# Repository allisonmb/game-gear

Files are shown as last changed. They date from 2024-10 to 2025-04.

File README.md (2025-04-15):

# Production Release - Game Gear
Our project was focused on recreating the original experience of the SEGA Game Gear handheld console with modern hardware and improved functionality.

[Build Instructions](Build%20Instructions.pdf)

[Bill of Materials](Bill%20of%20Materials.pdf)

[Raspberry Pi Image](https://drive.google.com/drive/u/0/folders/1cTOPLiqQtfveVBptVOEDtFShPZntb5K-)

Each aspect of the project is linked below, with README files indicating their functionality, how to run them, and known bugs.
- [Emulator ROM Implementation](romDev/)
- [Cartridge Auto Launch Scripts](romDev/udev_scripts/)
- [PCB Designs](https://github.com/allisonmb/game-gear/tree/17-pcb/pcbDesign)
- [GPIOnext](https://github.com/mholgatem/GPIOnext) - Used for interfacing with buttons through GPIO
- [3D Model](https://drive.google.com/file/d/1HNF1D_YHym1qWQATkMjLh69oOEiKL8Yn/view?usp=sharing) - Will need blender to view

Below are links to parts of the project that are no longer in development
- [FPGA Implementation](A-Z80/)
- [Z80 Assembly Test Code](<z80 assembly/>)

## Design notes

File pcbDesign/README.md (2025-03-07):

# PCB Design and Schematics
There are 3 PCBs: the left, right, and center PCBs. These are connected to eachother with header pins. Note: The "main PCB" is an old version which was before the PCB was split into 3. "GG PCB" is a remake of the original Game Gear PCB from https://oshwlab.com/maarten040476_3348/sega-game-gear-837-7996.
## Currently Implemented
### Center PCB
The center PCB connects to the left and right PCBs. 
The center PCB contains:
- [Raspberry Pi Zero W](https://www.raspberrypi.com/products/raspberry-pi-zero-w/)
- [3.5 Waveshare HDMI Screen](https://www.waveshare.com/wiki/3.5inch_HDMI_LCD)

### Left PCB
The left PCB contains:
- D-Pad buttons - These are traces on the board that are not connected. They are connected by a metal disk attached to the button that completes the circuit when the button is pushed.
- Power LED - A 3mm red LED with a 270 ohm resistor.

### Right PCB
The right PCB contains:
 - Start, 1, and 2 buttons - Works the same as the D-Pad buttons

## To be Implemented
### Center PCB
- Batery PCB - Need to decide on exact battery and battery board that will provide enough power for the other components

### Left PCB
- Volume Dial - Connected to rotary encoder that can be interpreted by the Raspberry Pi to change the system's volume level.
- Audio Amplifier - Connected to the Raspberry Pi and is capable of converting digital sound to anologue to go to a speaker. Currently looking at using [MAX98357A](https://www.adafruit.com/product/3006)

### Right PCB
The right PCB contains:
 - Brightness Dial - Same implementation as the volume dial, except for the screen brightness

## Current Issues
- The PCB is not complete, the parts listed above need to be added
- There may be an issue with using the MAX98357 audio amplifier with the PiJuice. Both use i2c for communication with the Raspberry Pi. However, they use different pins to do so and thus both may work together.
- The battery must be large enough to support the Raspberry Pi and the HDMI screen. The power consumption for both needs to be measured to choose a big enough battery.
- The largest single cell battery that can fit in the current case is 1200mAh. It is unlikely this is sufficient to power the console. There are two possible fixes for this. The case can be altered to allow a larger signle cell battery to fit, but this would cause issues with holding the console. Or multiple batteries in series could be used, but this would eliminate use of some battery PCBs which only work with single cell batteries.

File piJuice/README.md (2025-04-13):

# PiJuice Battery Setup

## Note - Ensure pijuice board is connected to the pi for the entire setup. The battery itself does NOT need to be connected to the pijuice

## 1. Install Lite Version of PiJuice Software
```bash
sudo apt-get install pijuice-base
```

## 2. Run PiJuice CLI
```bash
pijuice_cli
```

## 3. Choose Battery Profile
- Navigate to `Battery Profiles`
- Select: **PjZero_1200**

## 4. Configure Power Switch
- Navigate to `Buttons`
- Select `SW2`
  - Under **Press**, select: `HARD_FUNC_POWER_ON`
  - Under **Release**, select: `HARD_FUNC_POWER_OFF`

## 5. Configure LED Script

### a. Enable `pijuice.service`
```bash
sudo systemctl enable pijuice.service
sudo systemctl start pijuice.service
sudo systemctl status pijuice.service
```

### b. Ensure `lowPowerLED.py` Has Correct Ownership and Permissions
```bash
chmod +x /home/pi/lowPowerLED.py
chmod 777 /home/pi/lowPowerLED.py
sudo chown pi:pi /home/pi/lowPowerLED.py
```

### c. Set Script to Run on Boot
- Run `pijuice_cli`
- Navigate to `System Events`
  - Enable **System Start**
  - Set function to: `USER_FUNC1`
- Navigate to `User Scripts`
  - Set `USER_FUNC1` to:
    ```
    /home/pi/lowPowerLED.py
    ```

## 6. Configure Low Power Shutdown

- Navigate to `System Tasks`
  - Enable **Min Charge** and set threshold to **10%**
- Navigate to `System Events`
  - Enable **Low Charge**
  - Set function to: `SYS_FUNC_HALT_POW_OFF`

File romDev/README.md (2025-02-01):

# Emulator ROM Implementation
As part of our prototype we are developing a simple test ROM to run a "Hello World" demo program on any Game Gear Emulator. We are using DevkitSMS for this which is a library that allows c code to be compiled into Sega Master System and Sega Game Gear files. This process involves using a tool called BMP2Tile to turn a BMP image into readable tile and palette formats. The program uses the library's SMS_loadPSGaidencompressedTiles(), SMS_loadSTMcompresssedTileMap, GG_loadBGPalette(), SMS_displayOn(), and SMS_waitForVBlank() methods to load and display the "Hello World" background. SMS_AddSprite() is used to display a sprite of a Gator head which polls input from the directional pad and buttons to move around and change its image.

### Current implementation for final product
[Retropie](https://retropie.org.uk/) and the [lr-genesis-plus-gx](https://github.com/libretro/Genesis-Plus-GX) Game Gear emulator are currently running the test rom on a Raspberry Pi Zero W. The controller to interface with the raspberry pi is custom using an Arduino Feather with [GP2040-CE](https://gp2040-ce.info/) firmware which makes any microcontroller with a RP2040 chip recognized as a controller via USB.

The following steps are to install and run retropie and the test rom on a Raspberry Pi Zero W. Please look at the official documentation for retropie to make adjustments if running on a different raspberry pi.
1. Using [Raspberry Pi Imager](https://www.raspberrypi.com/software/) install an image of retropie onto a micro sd card. In the imager, select Raspberry Pi Zero W as the device, Emulation and Game Os > Retropie > Retropie (RPI 1/Zero) for the OS, and the micro sd as the storage.
2. On boot, a welcome screen should apear followed by a controller configuration screen. Configure the controller based on the instructions on the screen.
3. Enter Configuration > WIFI on the main menu. Select No on the next screen. Then select 1 Connect to WiFi network. After completing the following prompts, the pi is connected to the network. Return to the main menu.
4. Enter Configuration > RASPI-CONFIG. Select 3 Interface Options > P2 SSH. Select yes to enable SSH.
5. Download [compileTest.gg](compileTest.gg) from this repo onto a computer.
6. Use sftp to transfer compileTest.gg from your computer to the raspberry pi. The pi's IP address can be found under Configuration > Show IP.
7. Ssh into the raspberry pi. User is pi default password is raspberry. (NOTE: For security, this default password should be changed.) Move the compileTest.gg from the home directory to /home/pi/RetroPie/roms/gamegear
8. Restart retropie. This can be done by accessing the retropie menu with the start button
9. Game Gear will now be an option from the main menu. Select it then the compileTest rom

### How to run test emulator without a raspberry pi
1. Install Sega Game Gear Emulator, Fusion recommended (https://www.emulator-zone.com/doc.php/genesis/fusion.html)
2. Run makefile to compile code (if not already compiled)
3. In Fusion click File->Load Game Gear ROM (CTRL-A) and load "compileTest.gg"
4. Use arrow keys and 'A' to control program

### Setting Up the external controller
1. Program "/Keyboard/Keyboard.ino" to Arduino
2. Flash "/Keyboard/Arduino-keyboard-0.3.hex" to Arduino
3. Unplug and Replug Arduino to have it appear as a keyboard

### Bugs/History
#### Initial test rom development (using fusion)
There were some bugs throughout the development. One common mistake is using the Sega Master System color palette for Game Gear games. The color palette scheme is one of the few major differences between the two. When programming, bugs were a bit hard to detect with no terminal output from the fusion emulator. Luckily though compilation was very quick, requiring only one make command, so changes could be quickly made and tested. When learning how to display sprites, it was helpful to display all tiles of a sprite at once, and then sort from there which were needed and where.
#### Raspberry Pi Setup
There was one main issue implementing retropie on the Raspberry Pi Zero W which is easily avoidable. The main issue was downloading the incorrect version of Retropie. This resulted in the pi booting straight to the terminal instead of into retropie. 
Some current issues with Retropie include:
- Booting into the retropie main menu. Ultimately, this will need to boot directly to a Game Gear ROM or menu specifically for the Game Gear
- There are other emulators in retropie that are loaded on boot but are never used for this project. These need to be removed from the retropie install to reduce boot time and save space
- There is currently no exit built into the test rom. When running in retropie the test rom must be exited using the retroarch menu which is accessed using a hotkey configured at retropie's first boot. [Here is more information on the hotkey](https://retropie.org.uk/docs/Controller-Configuration/#hotkey)
- Using the GP2040-CE firmware on the Adafruit feather is not ideal. Significantly fewer gpio pins are configured on the Adafruit feather when installing the pico's version of the firmware on it (there is no adafruit feather version of the firmware). Thus, only 6 buttons can be configured on the custom controller with the Arduino Feather. The Game Gear has a total of 8 buttons. This is easily fixed by replacing the Adafruit Feather with a Raspberry Pi Pico

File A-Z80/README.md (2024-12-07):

# FPGA Implementation: A-Z80
Towards our goal of a realistic Game Gear representation, we intend to use an FPGA to replicate the Z80 and other boards such as the proprietary sound board. The [A-Z80](https://github.com/gdevic/A-Z80) does this, although it is somewhat outdated and does not have all of the functionality we need. However, it provides a full implementation of the Z80 along with some testing files. The implementation had to be updated from one that works on MAX II hardware to modern MAX 10 hardware (which is a jump from Quartus 13.0 to Quartus 23.1). As a result, the RAM and PLL (for the clock) had to be recreated in modern Quartus. Ultimately, this code is capable of converting a Z80 assembly file into a machine code memory initialization, synthesizing a memory and UART module, and then programming a DE10 Lite to replicate a Z80 that is running assembly code. The [provided test case](tools/zmac/hello_world.asm) is a "Hello World" implementation, which outputs printed statements over UART (in this case "CpE Design").

## How To Compile Assembly
1. Create and develop a Z80 assembly file in the [zmac folder](tools/zmac) (or use the provided [hello_world.asm](tools/zmac/hello_world.asm)).
2. Drag and drop the created assembly file onto [make_fpga.bat](tools/zmac/make_fpga.bat).
3. Proceed with synthesizing and programming below.

## How to Synthesize and Program the DE10 Lite
1. Open the DE10 Lite Quartus project located [here](host/basic_de1/basic_de1.qpf).
2. Ensure that the DE10 Lite development kit is selected as the board.
3. Ensure the pins are correctly assigned according to the [DE10 Lite manual](https://ftp.intel.com/Public/Pub/fpgaup/pub/Intel_Material/Boards/DE10-Lite/DE10_Lite_User_Manual.pdf).
4. Click the play sign at the top to perform synthesis, planning, and routing.
5. Open the Programmer and select the USB-Blaster device.
6. Remove the default file for programming and click add file. Then, navigate to output_files and select the .pof file.
7. Program the board.
8. Proceed to use the programmed FPGA.

## Using the Programmed FPGA (For the provided hello_world.asm)
- KEY0 will act as a reset, immediately resetting the programmed output (along with the counter).
- KEY1 will act as a non-maskable interrupt, spamming "IM2" and then continuing after KEY1 is released.
- The UART output can be visualized using a DAD board with WaveForms (through the 'protocol' menu), and will be on GPIO pin 6, with a baud rate of 115200, 8 data bits, 1 stop bit, no parity, and a CR LF as the end of line.

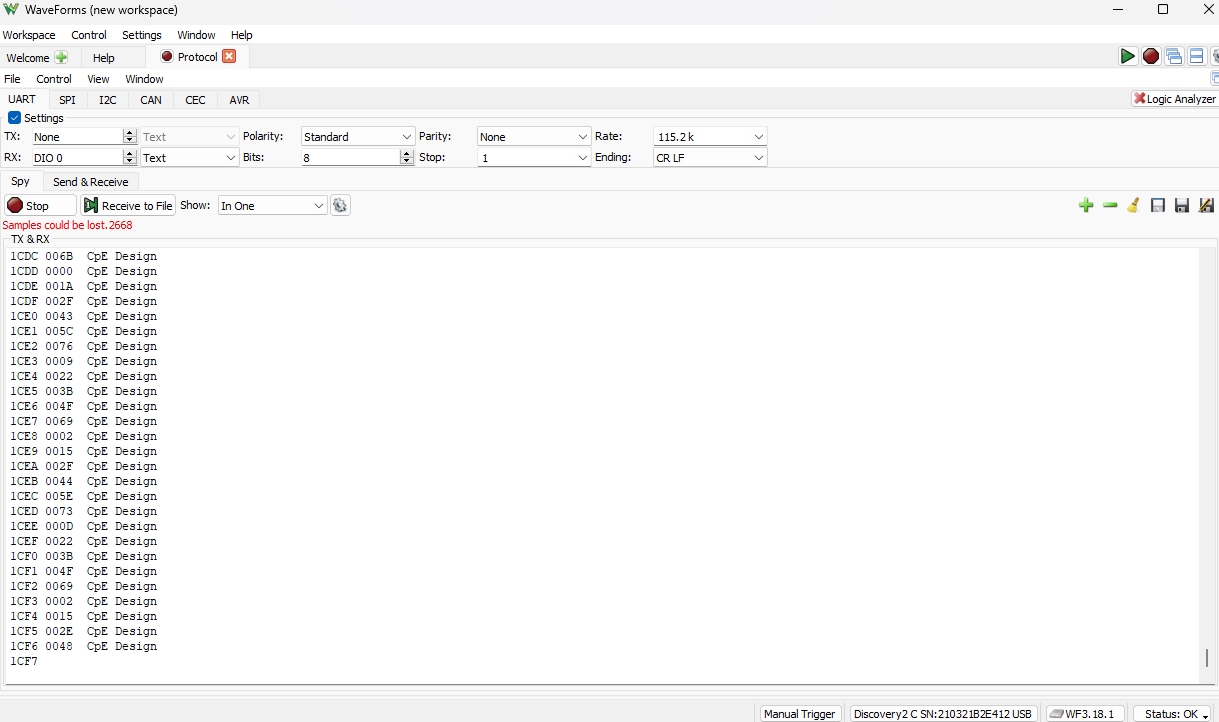
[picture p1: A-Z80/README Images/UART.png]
UART Output

## Experimentation/Difficulties
I struggled significantly with getting the A-Z80 code to run on any other board. At first, I tried the OOTB MAX 10 FPGA that was provided in Digital Logic, but was not able to get it to run even after many hours of modification. Ultimately, I realized this was because the particular model we were using did not support memory intiialization, and thus it was not possible to create a RAM to store the assembly and machine code that needs to run on the Z80. While I could program the OOTB FPGA with the A-Z80, I could not get any assembly code to run. As a result, I had to track down a DE10 Lite board (from Digital Design), which has the capability to create a RAM, along with several other useful features such as having switches, buttons, and VGA.

However, even with the DE10 Lite, there were still significant struggles. For some reason the A-Z80 implementation was made with the DE1 board in mind, which is in the MAX II family. This is an archaic board that is only supported by archaic versions of Quartus (when it was still called Altera Quartus), and my modern version of Quartus basically just told me to it couldn't do anything with respect to converting. As a result, I had to dig through the files myself, install Quartus 13.0sp1 (wow it's so old), and try to understand how to best recreate the IP files (RAM and PLL) in modern Quartus. For a while, it was hard to tell whether the struggles I was having were due to improper configuration of the codebase, errors due to the conversion to MAX 10, or something else. This was a bit of a nightmare to debug, and at first I just focused on getting the ModelSim implementation to work (which actually didn't take too long). Then, I eventually managed to get the DE10 Lite to output something that seemed like UART, although it wasn't recognized by WaveForms. Eventually, I realized that the RAM was still improperly configured, and managed to get Hello World to successfully print. Since then, I have also explored the possibility of video output (particularly through VGA), but the issue is that the existing implementation of VGA bases its timings on 24 MHz and 27 MHz clocks that were present on the DE1 board. However, the DE10 only has 10 MHz and 50 MHz clocks, and the VGA protocol is extremely sensitive to timing. As a result, implementing VGA video output would be a very complex endeavour. Furthermore, we aren't planning on using VGA in our final solution, so we decided to instead focus on other interfaces like UART, SPI, and I2C that we would actually use for our screen.

## Known Bugs/History
Synthesis can be a bit finicky in Quartus, and so some errors may appear on different versions of Quartus or with different FPGAs other than the DE10 Lite. This code will not run on boards that are not in the MAX 10 family without a decent amount of modification. Getting the UART code to properly output was challenging, but I was finally able to do so after significant trouble with porting from MAX II (which modern versions of Quartus do not support and cannot convert) to MAX 10. Ultimately, I had to delete the IP files and recreate them with as similar of settings and initializations as I could, and it took some trial and error. Thus, porting to other families may be similarly difficult. When starting Quartus, it may prompt to overwrite or update the database file from another version of Quartus, and this is normal and can be accepted.
   Additionally, there were some issues modifying the [UART test code](tools/zmac/hello_world.asm) to add load instructions to store the string in memory instead of using db, since in many applications the data may be loaded instead of being constant before sending it to a communication protocol. When adding additional load instructions, instructions at the end of the function block were skipped preventing the whole string from loading. This is possibly an issue with the eZ80Acclaim IDE which was used for debugging, but it is more likely to be a logic error in the assembly.

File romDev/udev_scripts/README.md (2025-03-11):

# Cartridge Auto Load Scripts
This directory contains the udev rule and correponsing systemd services and scripts to enable the automatic cartridge loading functionality of our system. When the user plugs in a cartridge, the cartridge is mounted, the .gg ROM file is found, and the ROM file is automatically loaded into the emulator. In addition, when the cartridge is removed the emulator will automatically quit.

# How to Use
1. First, copy the udev rule (99-external-storage.rules) from the etc/udev/rules.d folder to the corresponding directory (/etc/udev/rules.d) on the system. Make sure to change the hard-coded directories to have the right username.
2. Then, copy the systemd rules from etc/systemd/system/mount-cart@.service and etc/systemd/user/run-cart@.service to the corresponding directories. Once again, update the home directory usernames to match the current system.
3. Lastly, copy the scripts from the /home directory to the user's home directory (/home/*user*).
4. Restart to let the rules take effect, or run the following command: `sudo udevadm control --reload-rules && sudo udevadm trigger && sudo systemctl daemon-reload`.
5. Then, the udev rules should be fully functional.

# Known Bugs/Future Steps
Right now, this implementation looks for any USB device when deciding what to mount. Once we have the JoeyGG, we intend to expand the script by restricting it to only the UUID/manufacturer ID of the JoeyGG itself so that there are no false positives and negatives (for example auto killing the emulator when someone removes a flash drive).

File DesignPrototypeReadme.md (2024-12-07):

# Design Prototype
## FPGA Implementation

## Emulator Implementation

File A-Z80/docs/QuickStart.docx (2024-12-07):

# A-Z80 Quick Start

Windows setup; download and install the following tools:

Altera/Intel Quartus II Web Edition: https://fpgasoftware.intel.com OR

Xilinx ISE Webpack: https://xilinx.com/products/design-tools/ise-design-suite.html OR

Lattice ICECube toolchain from Synopsys.

For Altera DE1 board, the latest free version that supported Cyclone II was Quartus 13.0 SP1.

Download ModelSim from the same Altera/Intel site.

Python 3.5 (or newer): https://www.python.org/downloads

How do I add A-Z80 sources to my Z80-based project?

Run Python script “cpu/export.py” which will export all core CPU files to a directory of your choice. Then, add those files to your project. Instantiate a CPU using “z80_top_direct_n” module declared in the “z80_top_direct_n.v” file.

Note for the users of Lattice FPGA toolset: instead of “data_pins.v”, manually copy and use “data_pins_lattice.v file” instead.

How do I setup my Altera DE1 board to run Sinclair ZX Spectrum?

Flash the supporting ZX Spectrum combined ROM binary file (“host/zxspectrum_de1/rom/combined.rom”) into the board’s flash memory starting at the address 0. Use “DE1_ControlPanel.exe” utility from your DE1 CD disk (which you can also download from the Terasic’s site).

In Quartus: open, compile and flash “host/zxspectrum_de1/zxspectrum_de1.qpf” project.

Connect VGA, PS/2 keyboard and line-in to load Spectrum programs. Plug in a set of earphones to Line-out.

Select from thousands of ZX Spectrum games and load them by using Baltazar Studios’ PlayZX (http://play.google.com/store/apps/details?id=com.baltazarstudios.playzxtapes) app which can be found on Google Play store.

Still stuck?

Read the full User’s Guide.

Visit https://baltazarstudios.com, post a question and/or send me an email.

In any case – I would like to hear from you --

Hope you have fun using it as much as I had fun creating it!

Goran Devic

gdevic@yahoo.com

baltazarstudios.com Page 1

Copyright © 2014,2020 Goran Devic A-Z80

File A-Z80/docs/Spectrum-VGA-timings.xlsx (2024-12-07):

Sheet: Graphical
 |  | Sinclair ZX Spectrum on FPGA
 |  | VGA timings
 |  |  | Display area in 8x8 characters: |  |  | 32 | 24
 |  |  | Effective screen resolution: |  |  | 256 | 192 | doubled
 |  | 96 | 48 | 640 |  |  | 16
 |  | 96 | 48 | 64 | 512 | 64 | 16
2 | 2 |  |  |  | V-SYNC |  |  | 0
33 | 33 |  |  |  | BACK PORCH |  |  | 2
480 | 48 |  |  |  | Spectrum border |  |  | 35
 | 384 | H-SYNC | BACK PORCH |  | Spectrum display area (256x192) |  | FRONT PORCH | 83
 | 48 |  |  |  |  |  |  | 467
10 | 10 |  |  |  | FRONT PORCH |  |  | 515
 |  | 0 | 96 | 144 | 208 | 720 | 784 |  | 525
 |  |  |  |  |  |  |  | 800
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

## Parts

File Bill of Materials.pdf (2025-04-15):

Part | Quantity Needed 1 | PCB Identifier Center U1 | Link Raspberry Pi Zero W https://www.digikey.com/en/products/detail/raspberry-pi/SC0020/18150025
Header Pins 2x20 (40 pins total) 2.54mm pitch | 2 | | https://www.digikey.com/en/products/detail/amphenol-cs-fci/67997-240HLF/4273160
Rotary Encoder | 2 | Left; Right | https://www.digikey.com/en/products/detail/bourns-inc/PES12-40S-N0024/3780235
LED | 1 | Left D1 | https://www.digikey.com/en/products/detail/w%C3%BCrth-elektronik/151031SS04000/4489979
Capacitor | 7 | Right C1, C2, C3; Left C1, C2, C3, C4 | https://www.digikey.com/en/products/detail/murata-electronics/RDEC71E105K0P1H03B/4906171
Resistor | 1 | Left R1 | https://www.digikey.com/en/products/detail/vishay-beyschlag-draloric-bc-components/MRS16000C2200FCT00/7350454
2.54mm 1xn header pins | 1 | | https://www.digikey.com/en/products/detail/3m/961136-6404-AR/2071498
Switch | 1 | Right | https://www.digikey.com/en/products/detail/nkk-switches/AS11AP/1051311
PiJuice | 1 | Center U3 | https://www.digikey.com/en/products/detail/pi-supply/PIS-0586/13283428
Battery | 1 | | https://www.digikey.com/en/products/detail/pi-supply/PIS-1189/13283434
HDMI plug | 1 | | https://www.digikey.com/en/products/detail/adafruit-industries-llc/3548/7623050
Mini HDMI plug | 1 1 | | https://www.digikey.com/en/products/detail/adafruit-industries-llc/3552/7623054 HDMI ribbon cable https://www.digikey.com/en/products/detail/adafruit-industries-llc/3560/7623062
Silicone button pads | 1 | | https://www.amazon.com/LT-Easiyl-Conductive-Compatible-Replacement/dp/B0CQ4YH9D4
Speaker | 1 | | https://www.adafruit.com/product/1890?gad_source=1&gbraid=0AAAAADx9JvSbI8osgBGIcLq5hWuWV8ldh
Left PCB | 1 1 | | https://github.com/allisonmb/game-gear/tree/main/pcbDesign/filesForOrder/Left Center PCB https://github.com/allisonmb/game-gear/tree/main/pcbDesign/filesForOrder/Center
Right PCB | 1 | https://github.com/allisonmb/game-gear/tree/main/pcbDesign/filesForOrder/Right Case Battery Cover | 1 | https://drive.google.com/file/d/1TVWUaZFfJfGlUIiv-HNUUVC9Vxv84sXf/view?usp=drive_link Case Top | 1 | https://drive.google.com/file/d/1kTPAbAZTE-reKUjHF0lK-eGvGFzQNNjF/view?usp=sharing Case Bottom | 1 | https://drive.google.com/file/d/10rMt_GjwnyCPj9CBlOhWO_VZjm4s2Ax4/view?usp=sharing
JoeyGG | 1 | https://www.zedlabz.com/collections/retro-sega-game-gear/products/joey-gg-plug-play-writer-flasher-for-sega-game-gear-diy-pcb-usb-c-game-cartridge-backup-adapter-ben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 GameSlot | 1 | https://retrosix.co.uk/Game-Gear-GameSlot-Kit-p515558760 Glass Lens | 1 | https://retrosix.co.uk/Game-Gear-Glass-Lens-Black-p141380224
Button set | 1 | https://retrosix.co.uk/Game-Gear-Buttons-Original-p543971072
Screw set | 1 1 | https://retrosix.co.uk/Game-Gear-Stainless-Steel-Screws-p529555030 MPI 3508 HDMI LCD Screen https://www.aliexpress.us/item/3256806315105352.html
USB Type C to Micro USB cable | 1 | https://www.amazon.com/Qaoquda-Adapter-Converter-MacBook-Charging/dp/B099RBKDFF?th=1
Micro USB Left Angle extension Cable 2 Pack | 1 | https://www.amazon.com/Extension-Micro-B-Transferring-Suitable-Samsung/dp/B07MC7YSR2
3.5mm Male Plug Jack Connector to Bare Wire | 1 | https://www.amazon.com/dp/B0B19G67JP?ref=ppx_yo2ov_dt_b_fed_asin_title

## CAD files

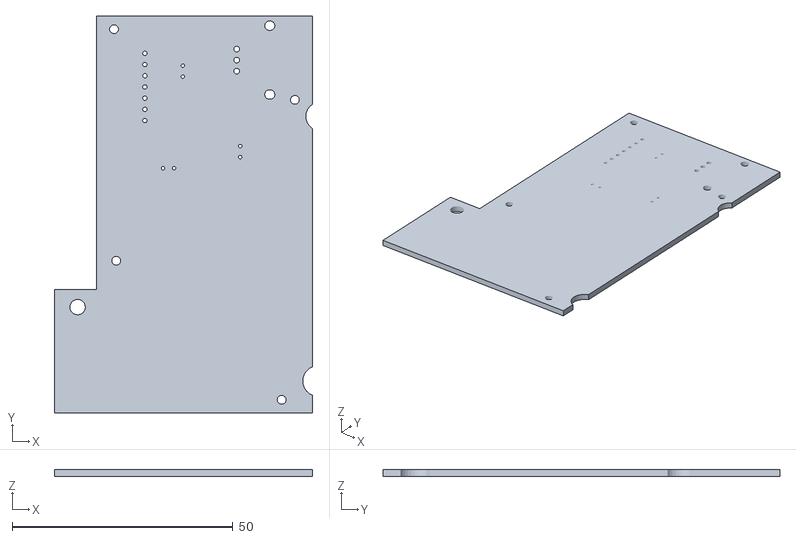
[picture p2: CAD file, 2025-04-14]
pcbDesign/rightPCB/rightPCB.stl
58.5 x 90.0 x 1.51

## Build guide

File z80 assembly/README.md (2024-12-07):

# Z80 Assembly

## IDE Testing code 
[This code](ideTesting/test.asm) was created to practice z80 assembly and learn the ez80Acclaim IDE. Mainly uses arithmetic and load instructions. Does not have much functionality

## Test code
[This code](TestCode/sega_print.asm) was created to ensure the majority of Z80 instructions worked with the ez80Acclaim IDE after issues with an online IDE (see bugs). This code makes use of 8-bit load, 16-bit load, 8-bit arithmetic, shift, rotate, call, jump, return, etc instructions. The code simply stores "SEGA Game Gear" in memory. However each character is calculated by using a combination of the instructions mentioned to ensure each instruction worked as intended. To ensure this, one instruction was added to the code at a time. Every time a new instruction was added, it was tested by running the code through the debugger and ensuring the registers and memory contained the intended value each time an instruction ran. 

## Car game
[This code](carGame/carGame.asm) was implemented to show that a game can be made with Z80 assembly alone. This game is run in the ZX Spin emulator. To run the code in the emulator load it at address 33000 (See Running the emulator below). The left control is space and the right control is left arrow key. The goal of the game is to avoid crashing the "car" into the walls. The main components of the code are keeping track of the score, displaying visuals, and the logic for the car and wall. A more detailed description of the program can be seen in the flow chart below[1].

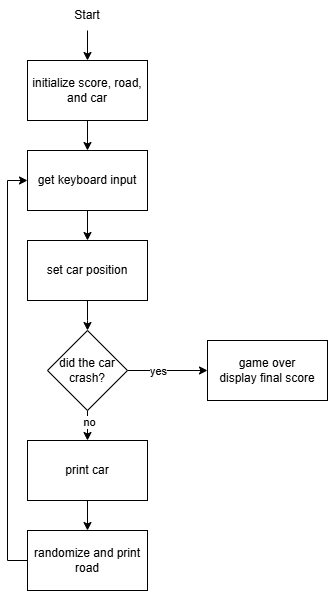
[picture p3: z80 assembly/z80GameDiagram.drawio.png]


## Assembly project set up for ez80Acclaim ide:
- IDE download available at: https://www.zilog.com/index.php?option=com_zcm&task=sdlp
### Create project:
1. Go to file and select new project
2. Select the path where the project will be created
3. Select "Assembly Only" for Project Type
4. Select "eZ80" for CPU Family
5. Select "eZ80190" for CPU
6. Select "Executable" for Build Type
7. Click Continue
8. Check eZ80DevPlatform_190_RAM. Leave the rest as default and click Next
9. Change the memory and storage blocks to the desired ranges and click finish

### Add files to project:
- Select Project->Add Files...
- Select the file to be added and click add. Can create a blank .asm file to be added. (Haven't found a way to create new files with the ide)
- The new file will be under the "Assembly Only Project Files" directory

### Debugging with the ide:
1. Build the code (Make sure it is built, not assembled. Only assembling the file will lead to an error when debugging).
2. Click go
3. Add breakpoints by cliking beside a line of code then clicking the Add/Remove breakpoint button
4. Click restart
5. Use step buttons to step through the code

### Debugging windows:
-To access the debugging windows go to View->Debug Windows

## Set up ZX Spin emulator
- Get the zip file download from https://www.zophar.net/sinclair/zx-spin.html
- Open the emulator using the exe file
- Go to Tools -> Z80 Assembler...
- Open an asm file with File -> Open
- Assemble the code with File -> Assemble

### Running the emulator
- Click in the emulator window
- Type: `100 t ctrl-shift l <address of code start>` and press enter
- Type: `r` and press enter

## Difficulties 
  Finding an IDE environment to develop z80 assembly was difficult since the z80 processor is obsolete and Zilog no longer provides a development environment for it. Initially, 3 different online assemblers were tested however none properly ran a load instruction. Then, we discovered the online IDE available at https://github.com/IgnacioSearles/Z80-AssemblerAndEmulator[2]. This seemed to work fine initially and we started to write the [sega_print.asm](TestCode/sega_print.asm) code. Initially, we only coded with 8-bit load and arithmetic instructions which worked fine in this IDE. To test that they worked fine, we debugged line by line to ensure the values in the registers and memory were as expected. However, we ran into issues when we tried to implement 16-bit load and arithmetic instructions which threw a compiler error despite matching the syntax from the z80 cpu manual[3]. We also tried to implement input and output instructions, however both threw compiler errors as well. When checking the documentation of the online IDE closely, we discovered documentation describing the instructions used in the IDE which did not include the input and output instructions. Even though this documentation stated 16-bit load and arithmetic instructions should work, we decided to look for a different IDE since we needed to compile input and output instructions [2]. 
  After another long period of searching, we found the eZ80 chip is backwards compatable with the z80 [4]. As a result, we tried the official Zilog development IDE for the eZ80 called ez80Acclaim, hoping it would build and debug z80 assembly. Input, output, and 16-bit load and arithmetic instructions worked without errors in ez80Acclaim which led us to continue developing in it. There were however a couple issues with this IDE, described in the "Bugs and issues" section below, that we took a while attempting to find a solution, however decided to continue developing the code since both issues could be easily tested when running on the FPGA.

## Bugs and issues
- In sega_print.asm, when returning from the called function (get65h) the value stored in the C register remains even after returning
- in ez80Acclaim IDE must write hex values as xh and cannot write them as $x. This differs in other IDEs.
- Possible issue: code assembled from the ez80Acclaim IDE may not work on the FPGA since it is technically compiling for the ez80. Safer to use solely as development environment and then move the asm files to the A-z80 assembler for implementation on the FPGA
- When using the ez80Acclaim IDE input and output instructions cannot be controlled. Input instructions are set to FF
- In the ez80Acclaim IDE the UART debug window does not properly recognize UART output
- The ez80Acclaim IDE can only use the z80 instruction set. Some of the code in this repo is writen in 8080 since the A-Z80 assembler is able to translate 8080 to z80. See FPGA readme
- The ZX Spin emulator will freeze and crash if code is edited while running an emulation
- The car game needs to be modified to work on the FPGA. Currently it is set up to communicate with the ZX Spin emulator which is written in BASIC. The FPGA implementation would need to be written to communicate with its hardware instead of the emulator.
- The car game controls are not intuitive. Currently to move left space is used and to move right the left arrow key is used
- Do NOT use online IDE available at https://github.com/IgnacioSearles/Z80-AssemblerAndEmulator. This IDE does not implement input or output instructions and 16 bit arithmetic instructions are bugged [2].

## References
[1]  J. Kingsman. “Tutorial: ZX Spectrum Machine Code Game in 30 Minutes.” Chutney. Available: https://chuntey.wordpress.com/2010/01/12/tutorial-zx-spectrum-machine-code-game-30-minutes/

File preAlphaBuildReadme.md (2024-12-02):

# game-gear

## Architecture
### PCBs and Hardware Overview
The game gear is made up of 3 PCB boards: The back board (or main board), DC-DC converter board, and sound board. The majority of components are contained on the back board, including the main memory (IC3), video memory (IC2), and ASIC (IC1). The ASIC chip is owned by Sega, and thus must be recreated. [1]

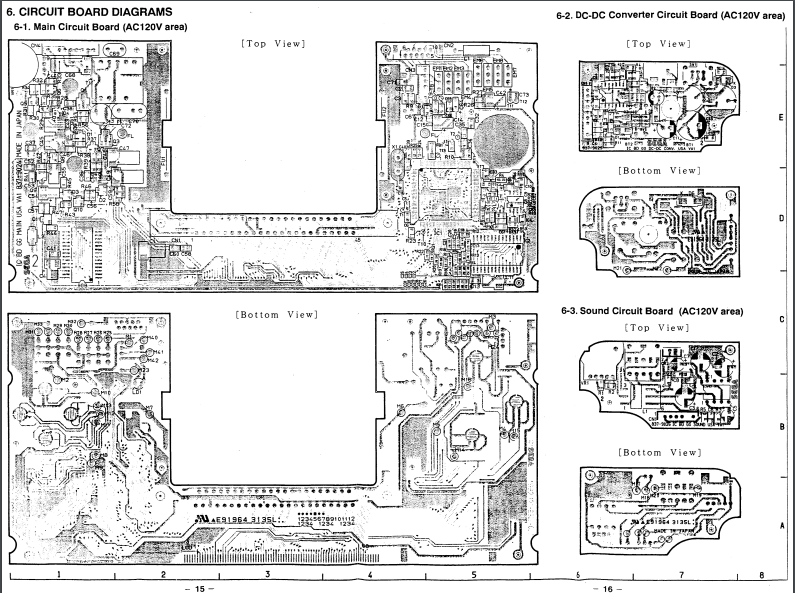
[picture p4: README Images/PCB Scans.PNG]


Figure 1: Scans of the PCB boards [1]

### ASIC - IC1
The ASIC chip is essentially the processor for the game gear. The main components in the ASIC are the CPU (z80), video display processor, standard cell array. The remainder of the components can be seen in the block diagram below. Asside from the z80, none of these components have a part number and thus will have to be recreated or replaced [1]. Many of these components will be placed on the orange crab fpga, which will essentially replace the ASIC.

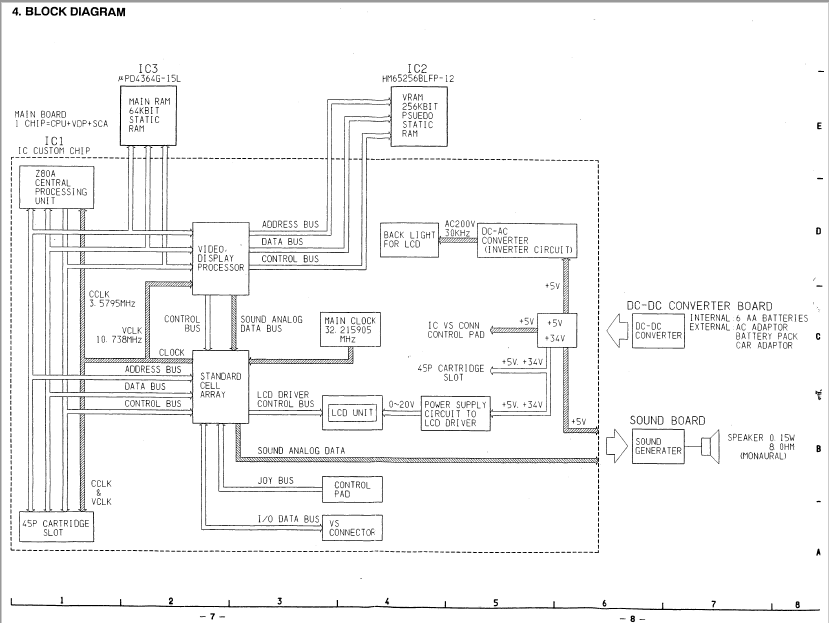
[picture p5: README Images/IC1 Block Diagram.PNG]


Figure 2: Block diagram of the contents of the ASIC chip and its connections to other subsystems [1]

### Memory - IC2, IC3, and the game cartridge
The memory included in the game gear itself are the main memory and video memory chips. The main memory is a 64kBit CMOS SRAM and the video memory is a  256kBit pseudo SRAM [1]. Since the specific chips used in the game gear are no longer availible, they must be replaced with another suitable RAM chip. The main memory has been replaced by a 256kBit CMOS SRAM with nearly exact read/write cycle timing to the original [2]. 

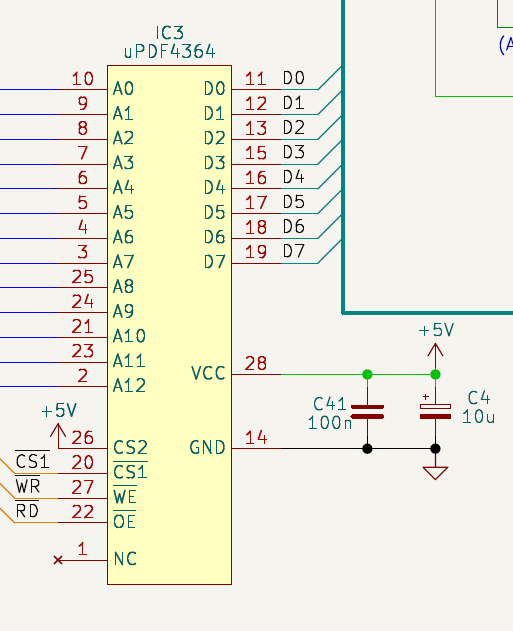
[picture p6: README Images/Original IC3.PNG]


Figure 3: Original IC3 chip [3]

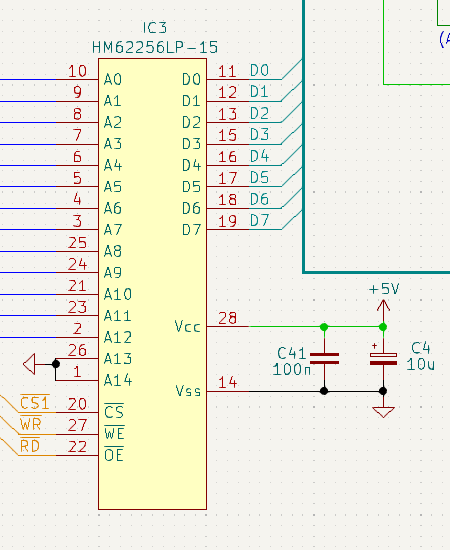
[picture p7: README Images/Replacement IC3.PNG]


Figure 4: Replacement IC3 chip

The game cartridge contains the data for the game itself and can be swapped out of the console. This recreation of the game gear will work with original game gear cartridges. It is possible to create a custom game gear cartridge, however it is difficult since it contains a Sega proprietary chip [4].

### Video
The game gear has a 3.2 inch backlit 256x192 resolution LCD screen using vga communication [5]. Since it is nearly impossible to find a screen of this resoultion today, a higher resolution screen will be used and the graphics adjusted accordingly. 

### Sound
The sound chip on the game gear is a SN76489 with four channel mono sound and three square wave generator outputted through one speaker in the console [6]. The majority of the components for the sound are contained on the sound board [1]. The SN76496 is obsolite so it will be recreated through emulation. It is also possible to play sound through the headphone jack on the top of the console which will be included in this recreation.

### Inputs
#### Buttons
There are a total of seven buttons on the game gear which are used to control gameplay [1]. All of these are simple push buttons connected to the back board PCB [3]. There is also a basic power switch [1].

#### Dials
The game gear contains two dials for brightness and volume. They are connected to the back board PCB and sound PCB, respectively [1].

#### Plug in connections
At the top of the console there is a headphone jack, gear-to-gear cable input, and power jack input. The headphone jack is a standard aux plug which will output sound to any device connected to it [1]. The gear-to-gear input is used to connect two game gears together to play multiplayer games [7]. The power jack input is used power the console with a cable wall adapter instead of with the batteries.

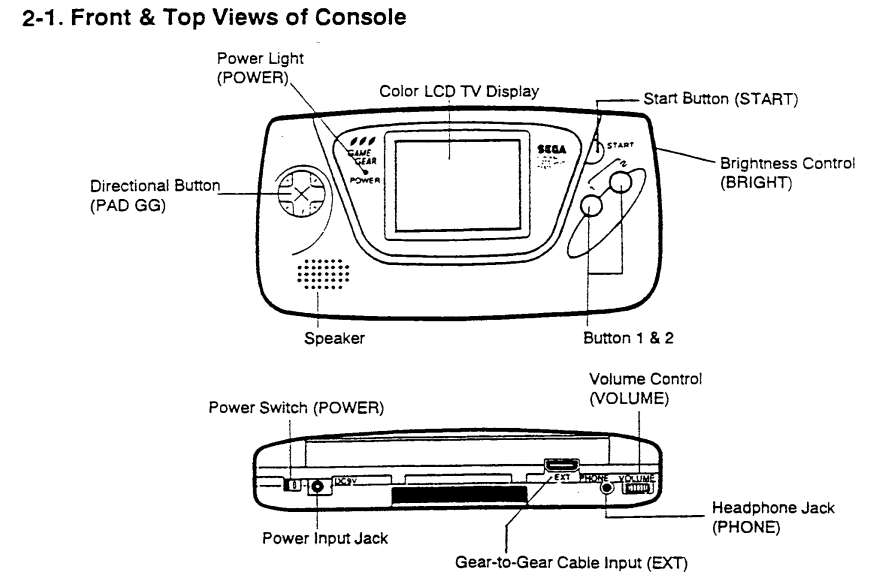
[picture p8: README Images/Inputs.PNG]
 

Figure 5: All inputs for the game gear [1]

### Emulator Work
As part of our prototype we are developing a simple test ROM to run a "Hello World" demo program on any Game Gear Emulator. We are using DevkitSMS for this which is a library that allows c code to be compiled into Sega Master System and Sega Game Gear files. This process involves using a tool called BMP2Tile to turn a BMP image into readable tile and palette formats. The program uses the library's SMS_loadPSGaidencompressedTiles(), SMS_loadSTMcompresssedTileMap, GG_loadBGPalette(), SMS_displayOn(), and SMS_waitForVBlank() methods to load and display the "Hello World" background. 

## Completed components
IC3 - Main RAM

## In progress
Sound Chip
Back Board Schematic/PCB
LCD Screen

## Not started
### ASIC chip
Visual Display Processor
Standard Cell Array
Main Clock
DC-AC Converter

### Other components
DC-DC Converter Board Schematic/PCB
Sound Board Schematic/PCB
Speaker
IC2 - VRAM
Cartridge

## Known Bugs
### IC3 - Main RAM
Possible timing issue due to the difference of some values in the read/write cycle for the replacement RAM. These values are: output hold from address change, chip selection to output in low z, write recovery time, and output active from end of write. This is unlikely to cause problems since the replacement RAM is faster and the difference is small (5ns).
### FPGA HDL Flashing
Synthesis and routing on FPGAs can often be a bit finnicky, especially depending on the pipeline being used. Thus, there is the potential that issues arise when our results are translated to the OrangeCrab board with a Lattice FPGA. Similarly, the pinout is different for Lattice and many of these files (A-Z80) were intended for Intel FPGAs, so we may have to do some tweaking to reconfigure it. Similarly, Quartus cannot be used for the Lattice FPGAs, and as a result for OrangeCrab we need to use the Open Source FPGA toolchain with Yosys and NextPnR. We expect that issues will arise when we transfer things over to the actual FPGA for our final product.
### Sound Chip Imperfections
Currently, the waves produced by our emulated sound chip are perfect and ideal square waves. However, in the real world this is likely not the case. As a result, for optimal recreation of the original hardware, we should try to emulate this imperfection somehow. For instance, making jumps slightly more progressive (add some delay time) rather than instantaneous or shifting the offsets of our signals.

## References
[1]  Sega, "Sega Service Manual Game Gear VA1," December 1993. [Online]. Available: https://gamesx.com/wiki/lib/exe/fetch.php?    media=schematics:service_manual_-_game_gear_va1.pdf. [Accessed 24 October 2024].

[2]  Major Brands, "HM62256 Series," [Online]. Available: https://www.jameco.com/Jameco/Products/ProdDS/42850.pdf. [Accessed 24 October 2024].

[3]  J. Lewis (2023) "bit-preserve" (Version 1.0) [Souce code]. https://github.com/baldengineer/bit-preserve/tree/main/Sega/Game%20Gear.

[4]  G. O’Brien, "DIY SEGA Game Gear 512Kb Flash Cartridge," October 2010. [Online]. Available: https://www.smspower.org/uploads/Development/DIY_SEGA_Game_Gear_512Kb_Flash_Cartridge.pdf. [Accessed 25 October 2024].

[5] Luke from RetroSix, "VA0/VA1 LCD Interface (Game Gear)," Retrosix, 16 December 2023. [Online]. Available: https://www.retrosix.wiki/va0va1-lcd-interface-game-gear. [Accessed 25 October 2024].

[6] "Sega Master System/Technical specifications," Sega Retro, [Online]. Available: https://segaretro.org/Sega_Master_System/Technical_specifications. [Accessed 23 October 2024].

[7] "Gear-to-Gear Cable," Sega Retro, [Online]. Available: https://segaretro.org/Gear-to-Gear_Cable. [Accessed 25 October 2024].

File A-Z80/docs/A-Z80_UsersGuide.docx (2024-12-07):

# A-Z80 CPU User’s Guide

An FPGA project recreating the Z80

© 2014-2020 Goran Devic

3/4/2020

# Revision History

Date | Revision | Change
2014-12-14 | 1.0 | Initial revision.
2014-12-21 | 1.1 | Added ZX Spectrum Turbo mode, speaker blink etc.
2015-01-22 | 1.2 | Added section on file generators; other small updates.
2016-03-06 | 1.3 | Added Xilinx support.
2017-01-07 | 1.4 | Corrections and update.
2018-03-10 | 1.5 | Corrections and update.
2020-03-04 | 1.6 | Corrections and update.

# Introduction

A-Z80 is a conceptual implementation of the venerable Zilog® Z80 processor targeted to synthesize and run on a modern FPGA device. It differs from the existing Z80 implementations in that it is designed from the ground-up through the schematics and low-level gates.

This design is capable of mimicking the actual Z80 CPU and, through its architecture, it illustrates its inner workings.

The A-Z80 implementation strives to be internally structurally identical to the original Z80. Using this approach, the model achieves a full cycle accuracy and has identical behavior for all documented and undocumented features (*). This is achieved not by explicitly hard-coding exceptions and quirks, but by mimicking the actual design.

Various Zilog Z80 references are widely available so the CPU, its instructions and behavior, will not be covered in this document.

This document focuses on the structure and mechanics of working with the A-Z80 model; it should help you understand it, incorporate it into your designs, and even modify it, should you wish to experiment with it.

You can read more about the conception and implementation of the A-Z80 on its home website: https://baltazarstudios.com .

If you simply want to integrate A-Z80 CPU into your own project, you can skip to section Integration.

# Project Directory Structure

A-Z80 project can be downloaded from two locations:

- OpenCores (SVN): https://opencores.org/projects/a-z80
- GitHub (git): https://github.com/gdevic/A-Z80

The following table describes the directory structure:

Directory | Sub-directory | Description
cpu | | Contains the core files of the A-Z80 CPU
| alu | Arithmetical and Logical Unit files
| bus | Various bus-related files
| control | Control unit files
| registers | Register block files
| toplevel | A-Z80 top level interfaces and projects
docs | | Documentation and images of schematics
host | | Several implementations using A-Z80 on Altera and Xilinx boards
| basic_de1 | Basic computer for testing and verification, uses UART, Altera DE1
| basic_nexys3 | The same but for Xilinx Nexys3 board
| zxspectrum_de1 | Sinclair ZX Spectrum implementation for Altera DE1 board
resources | | General project resources and scripts
tools | | Building and testing utilities and misc. files
| Arduino | Software for Arduino Mega dongle to interface with a Z80
| dongle | Dongle and simulation scripts and golden files
| z80_pla_checker | Windows utility to test and create A-Z80 PLA tables
| zmac | Z80 test and verification assembler files

# Environment

A minimal set of tools needed to compile various parts of the project is:

- Altera Quartus II Web Edition (free) OR
- Xilinx ISE Webpack (free) OR
- Lattice ICECube toolchain from Synopsys
- ModelSim (Altera edition, free) – needed for simulation of various modules
- Python 3.5 (or newer) – needed to change or recompile A-Z80 files
- Microsoft Visual Studio 2015 or newer, or mono – needed to recompile the z80_pla_checker tool (written in portable C# code)

If you are only going to use A-Z80 in your project, all Verilog files that you need are already checked in and ready to be included and you don’t need any of the extra tools listed. Use Python script “export.py” to copy/export necessary files for you (don’t copy files manually since only some files are needed and the script ‘knows’ which ones).

This project was developed and tested on a 64-bit Windows 7 OS. Most recently, it has also been worked on and tested on Windows 10 and Linux Mint 19 (with Quartus tools).

Your mileage may vary on other platforms.

# Test Boards

Altera: Designs are tested on a Terasic DE1 board:

https://www.terasic.com.tw/cgi-bin/page/archive.pl?No=83

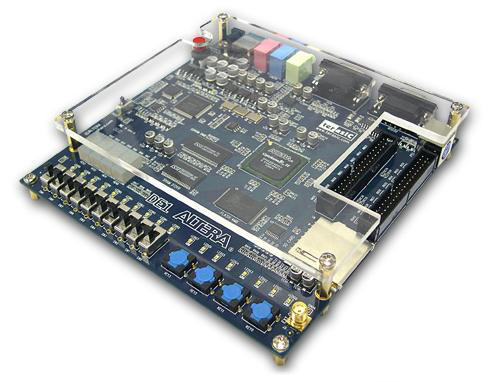
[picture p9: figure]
Figure 1. DE1 Development Board

This board, which has been phased out, has a Cyclone II EP2C20F484C7 FPGA alongside several useful peripherals including a 512 KB SRAM bank, PS/2 keyboard, UART and a VGA connector. It is ideal for development of a retro designs.

Xilinx: Designs are tested on a Digilent Nexys3 board:

http://store.digilentinc.com/nexys-3-spartan-6-fpga-trainer-board-limited-time-see-nexys4-ddr/

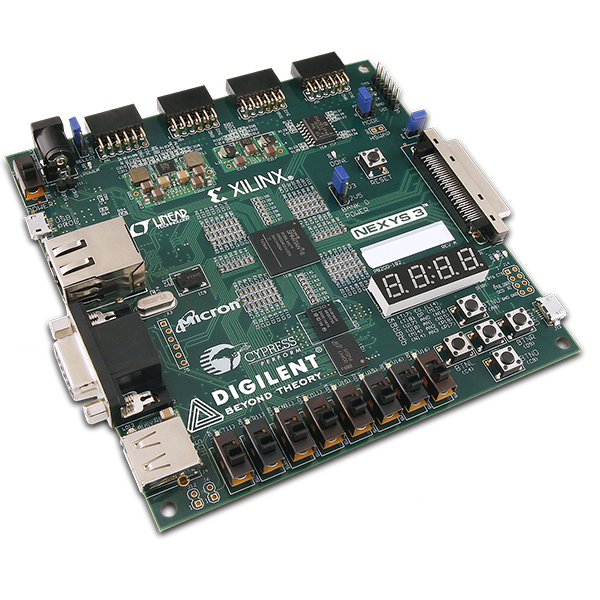
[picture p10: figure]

This board, which has also been retired, features a Spartan-6 XC6LX16-CS324 FPGA and several useful peripherals such are UART, PS/2 keyboard and VGA.

# Simulation

## Module simulations

If you make any change to the CPU core files, you should run one or more simulations to verify the correctness of your modifications.

Each module in the “cpu” directory contains a ModelSim simulation project that verifies the functionality of one or more of its blocks. Before opening a project in ModelSim, run “modelsim_setup.py” script located in the project root directory. That script will set up relative file mappings to enable project to reside anywhere on your drive.

If you have installed and configured ModelSim correctly, double-clicking on any *.mpf file will open a project in the ModelSim GUI.

This example will illustrate setting up and starting a simulation of a specific logic block in the alu module.

Before you can compile a simulation test bench, create a library by typing “vlib work” as shown:

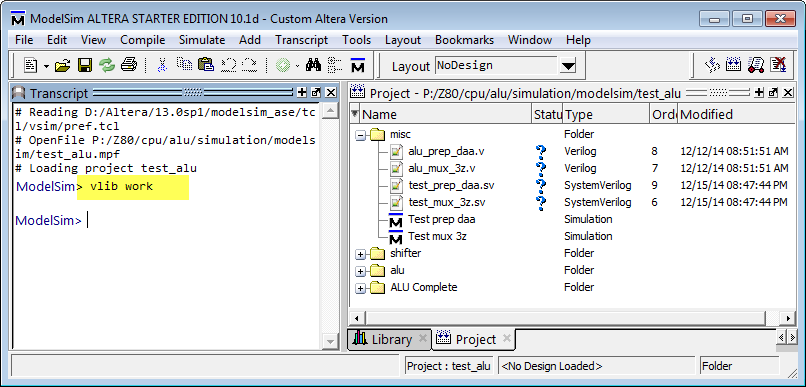
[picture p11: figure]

Next, select “Compile->Compile All” to compile all files that are part of a module simulation.

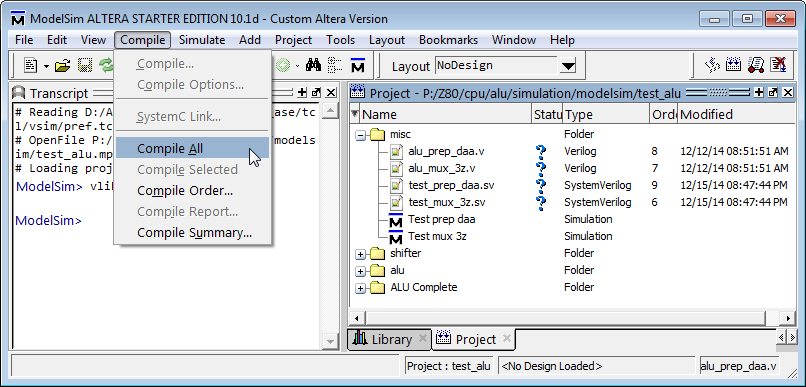
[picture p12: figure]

Each project has one or more simulation configurations; each configuration tests a specific block of logic. In addition, each configuration has its own wave file which you can load before you run a simulation. Wave files are customized for a specific test and provide a handy way to quickly see all relevant signals.

In this example, we will run “Test prep daa” configuration. DAA is a Z80 instruction that adjusts accumulator for a decimal operation. It requires calculating the adjustment addend based on the result of a previous operation. Hence, this test is written to verify the correctness of that calculation.

Each test configuration is run by a main test bench file that is always written in a System Verilog language with the extension *.sv. A file that runs the “Test prep daa” configuration is “test_prep_daa.sv”.

Double-click on the “Test prep daa” configuration and your simulation should be loaded.

Open the wave window if it is not already visible and select File->Open to load a wave file as shown:

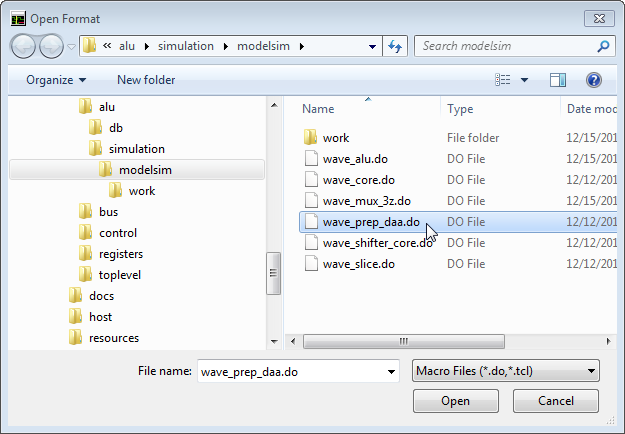
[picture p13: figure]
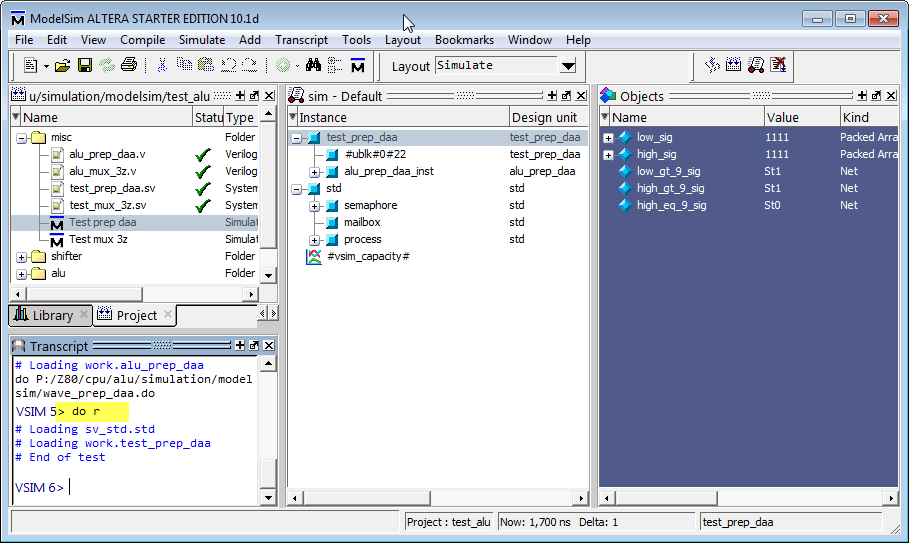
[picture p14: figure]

A shortcut is provided to run simulation: each ModelSim directory contains a small text file with the name “r” that contains command “restart -f ; run -all”. Run, or rerun, a test simply by typing “do r” as shown above.

After running this example, you should see a waveform of the DAA preparation block:

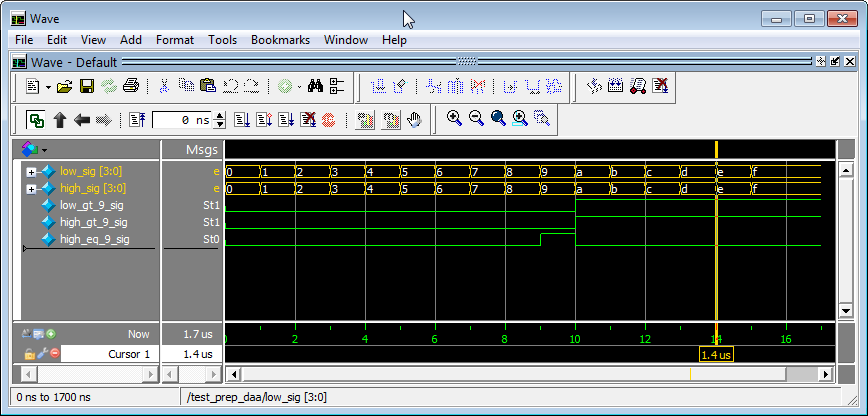
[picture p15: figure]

Although a very simple, this example hopefully illustrated a method of running a simulation. The same process can be repeated with other configurations and modules. The pattern of configurations, files and waveform names is the same.

Each main test bench file (just like the “test_prep_daa.sv”) contains a set of assert() statements to verify the signal correctness. These asserts will fail and your simulation will stop if the signals take unexpected values.

Most simulations run for a predetermined number of clocks. The exceptions are top-level simulations (in the directory “cpu\toplevel\simulation\modelsim”) and a basic host simulation (in the directory “host\basic_de1\simulation\modelsim”). These simulations need to be stopped manually since they simply continue to execute given Z80 executable code.

## Top-level simulations

The two top-level simulations are designed to load an arbitrary Z80 assembly code and execute it. A simple unidirectional UART model is provided for the Z80 software to write to the ModelSim console. The UART model will simulate behavior of a synthesized serial port. When the same design is synthesized for the FPGA, the same Z80 code will write messages through a physical serial port.

UART is using 115200 baud data transfer rate, 8 data, 1 stop bit, no parity.

Module | Simulation project
Toplevel | cpu\toplevel\simulation\modelsim\test_top.mpf
Basic host | host\basic_de1\simulation\modelsim\test_host.mpf

Those two simulation configurations can run any Z80 code; several sample test sources can be found in the directory “tools\zmac” along with ZMAC assembler and a few batch scripts that simplify compilation and the test setup. Z80 test files are somewhat based on CP/M and have a BDOS style text print interface.

Two MS DOS batch files are used to compile and run tests:

Batch file | Description
tools\zmac\make_modelsim.bat | Compiles and generates executable code for a ModelSim test at “cpu\toplevel\simulation\modelsim\test_top.mpf”, for “test_top” configuration.
tools\zmac\make_fpga.bat | 1. Compiles and generates executable code in Intel HEX file format to be included into the target FPGA data file for basic host “host\basic_de1\ host_board.qpf” 2. Also generates executable code for the basic host ModelSim test at “host\basic_de1\simulation\modelsim\ test_host.mpf”

You can create your own Z80 assembly tests to run: simply drag and drop an assembly source file onto one of those two batch files and they will compile a file and copy the results into proper target directories.

For this example, we will compile and run a “Hello, world” test (“tools\zmac\hello_world.asm”).

Drag and drop “hello_world.asm” onto the “make_modelsim.bat” and start a top-level simulation (“test_top” configuration) in the ModelSim.

Shortly, you should see the output in the ModelSim console window.

After you see the text being written to the virtual UART device, you can stop the simulation.

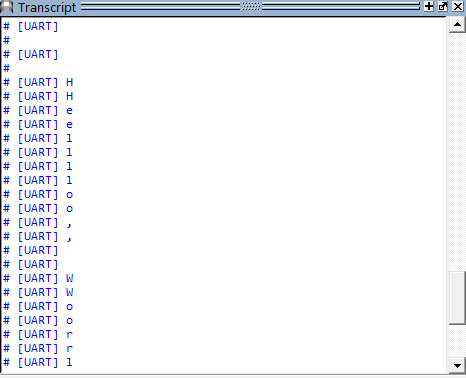
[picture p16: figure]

# Verification

## Fuse tests

Fuse is a set of tests to verify Z80 at the individual instruction level. Written for software emulator designers, it contains a fairly complete set of input and output states for each instruction.

Files that are used in this verification are subset of the Fuse emulator source package: http://fuse-emulator.sourceforge.net . You can find them in the “cpu\toplevel\fuse” directory.

The files describe individual instruction’s tests and need to be processed into a format that we can run – which is Verilog. A Python script “cpu\toplevel\genfuse.py” generates Verilog test code for a selected number of Fuse tests.

See that script file for more details on how to configure it before running.

When run, it creates “cpu\toplevel\test_fuse.vh” include file.

// Automatically generated by genfuse.py

force dut.reg_file_.reg_gp_we=0;

force dut.reg_control_.ctl_reg_sys_we=0;

force dut.z80_top_ifc_n.fpga_reset=1;

#2 //--------------------------------------------------------------------------------

force dut.instruction_reg_.ctl_ir_we=1;

force dut.instruction_reg_.db=0;

#2 release dut.instruction_reg_.ctl_ir_we;

release dut.instruction_reg_.db;

$fdisplay(f,"Testing opcode 00 NOP");

Once generated, this include file needs to be compiled with a ModelSim project file “cpu\toplevel\simulation\modelsim\test_top.mpf” to run a set of tests. The test output will show in the ModelSim window and the test will also create and write a file “fuse.result.txt”.

Hint: You can speed up Fuse simulation if you disable output to the wave window by typing:

VSIM 10> nolog –all

The following command re-enables the output:

VSIM 10> nolog –reset

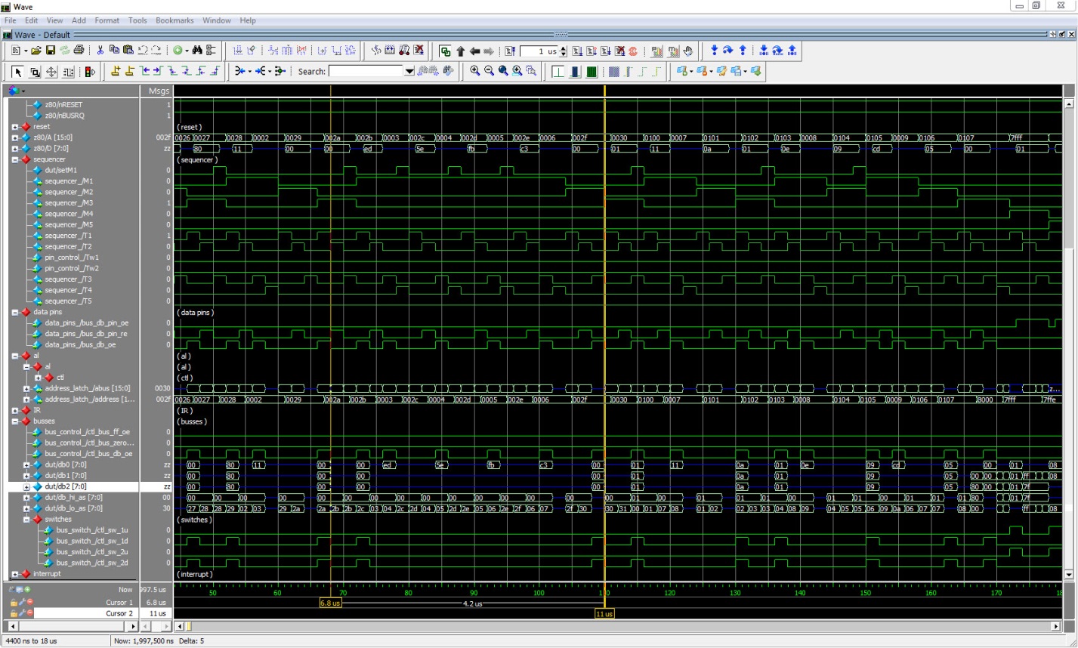
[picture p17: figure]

Image 1 : Fuse tests in ModelSim

Results of Fuse tests are written in the file “fuse.result.txt”, one instruction per line:

Testing opcode 00 NOP

Testing opcode ed67 RRD

Testing opcode ed6f RLD

Testing opcode 81 ADD A,C

Testing opcode cb41 BIT 0,C

Testing opcode cb93 RES 2,E

## Selected functional tests

There are 3 tests that verify specific ALU operations by cross-checking the results run on a real Z80 with the algorithm written in Python:

Test directory | Z80 test file | Description
tools\dongle\daa | tools\zmac\test.daa.asm | Execute DAA instruction for all values 0-255
tools\dongle\neg | tools\zmac\test.neg.asm | Execute NEG instruction for all values 0-255
tools\dongle\sbc | n/a | Simulate SUB and SBC instructions

Python scripts run the Arduino Z80 dongle (described in the Tools section) and generate output files. Those files are then compared with the output produced by another set of Python scripts (they implement corresponding algorithms). Lastly, the same text files are compared with ModelSim simulation of those instructions and by running the same executable on the Simple Host FPGA implementation and capturing the UART output.

The “golden” files include values of flags and accumulator going into the instruction and the result after the instruction has completed:

F:00 A:00 -> 00 F:44

F:00 A:01 -> 01 F:00

F:00 A:02 -> 02 F:00

F:00 A:03 -> 03 F:04

F:00 A:04 -> 04 F:00

F:00 A:05 -> 05 F:04

F:00 A:06 -> 06 F:04

F:00 A:07 -> 07 F:00

## Z80 Assembly level tests

Folder “tools/zmac” contains several Z80 assembly level tests.

Test source file | Description
tools\zmac\hello_world.asm | A mandatory “Hello, World”
tools\zmac\zexdoc.asm | Tests documented Z80 instructions and flags
tools\zmac\zexall.asm | Tests ALL Z80 instructions and flags (documented and undocumented)

While all of them can run in ModelSim, the last two are comprehensive and very long tests which should normally be run only on an FPGA hardware in full speed mode.

“hello_world.asm” is written to allow test bench “cpu\toplevel\test_top.sv” to exercise various interrupt modes. It contains interrupt handlers and logging for the test bench to run the following cases:

- Inject a single or periodic NMI
- Inject a single or periodic INT
- Test response to the nWAIT signal
- Test response to the nBUSRQ signal
- Test resets

# Tools

## PLA Checker Tool

PLA checker tool in “tools\z80_pla_checker” directory is a test utility to verify and create PLA code used to statically decode Z80 instruction groups.

Since you normally don’t have to compile that code, the executable file is checked in. This is a .NET application which should equally well run on Windows and Linux with mono support.

The PLA checker tool loads several files from the “resources” directory. That includes a raw PLA table definition which was reverse-engineered from an image of a Z80 die.

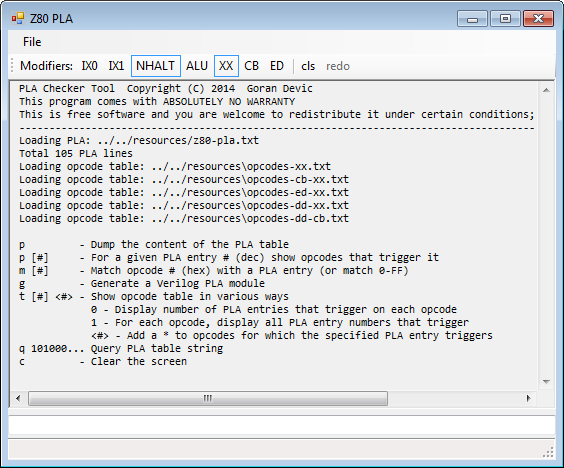
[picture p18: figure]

The tool was invaluable in the development of A-Z80 and maintain its value as a cross-checker for the PLA code. Available commands are:

Cmd | Description
h or ? | Help, list all commands.

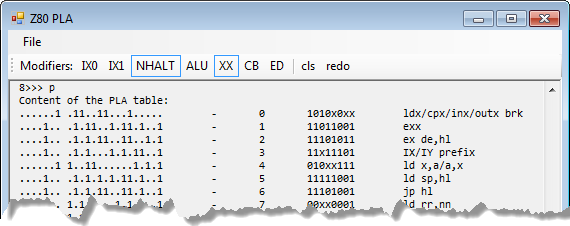
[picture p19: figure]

p | PLA table contains a set of modifiers and a gate-level logic array that ‘filters’ various instruction opcode groups. This command shows you those groups.
p # | Given a PLA entry number (decimal), show opcodes that are activated by it 10>>> p 3 PLA Entry: 3 Modifier: XX, NHALT DD => [3] IX/IY prefix FD => [3] IX/IY prefix
m # | This is a reverse-lookup that shows all PLA table entries that would activate a specific opcode given as a hex number: 12>>> m 76 Opcode: 76 [58] ld r,(hl) [59] ld (hl),r [61] ld r,r' [95] halt

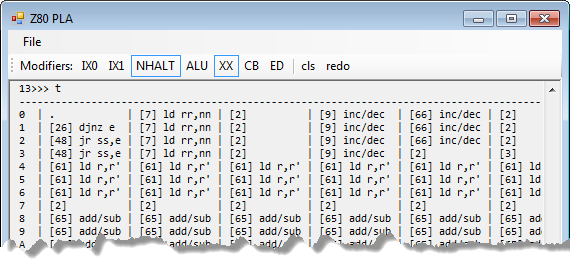
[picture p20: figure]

t | Dumps the opcode table in several ways. One or two optional arguments are given which restrict the table or show extra information including the number of PLA entries that trigger for each opcode etc.
q # | Useful only while simulating the CPU design, this command decodes the actual PLA table string which is a long sequence of binary digits (105 bits in total)

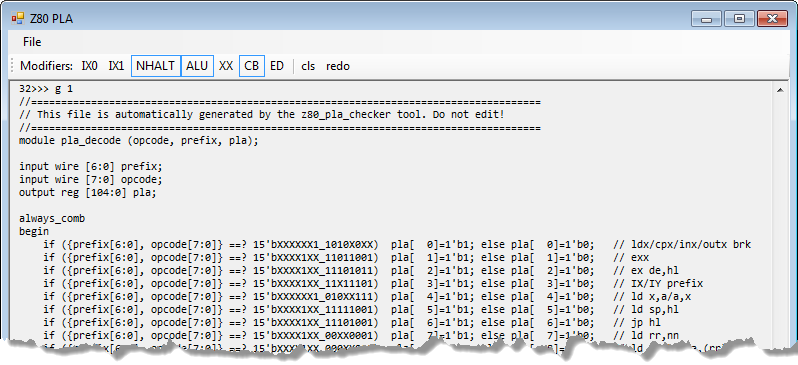
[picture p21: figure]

g | Generates Verilog code that implements the PLA decode. The output of this command is used to create “cpu\control\pla_decode.sv” source file which is at the core of the design. The image shows the start of the PLA decode module implemented in Verilog.

Z80 has several opcode tables and addressing modes selected either by a combination of instruction prefix bytes (0xCB, 0xED and IX/IY) or by the internal state (HALT, ALU…)

PLA checker tool lets you set or unset any of these modifiers:

The modifier buttons directly correspond to modifiers in the PLA table and let you simulate the exact PLA logic behavior as you are executing various tool dumps.

The tool keeps a history of commands that are typed in; a number displayed at the front of a prompt “>>>” is a location in the history buffer. Pressing PgUp and PgDown selects a command from the history buffer; ESC clears the command line.

## Arduino Tools

Directory “tools\Arduino\Z80_dongle” contains firmware for the Arduino Mega connected to a Zilog Z80 through a custom dongle. This setup can be used to pace Z80 in a controlled way and to execute individual instructions and monitor bus activity. You can read more about that dongle in this blog: https://baltazarstudios.com/arduino-zilog-z80

It was heavily used to generate tables for the correct bus behavior. These tables and Python scripts to create them are checked in the directory “tools\dongle”.

# Integration

This section describes how to integrate A-Z80 CPU into your own project.

The method is tested with Altera and Xilinx design tools on several test boards. Other users contributed by using a variety of boards, including Lattice-based FPGA boards.

The process of integration involves adding all relevant source files and setting up interfaces. For convenience, all files needed to synthesize a CPU are listed in the file “cpu/top-level-files.txt” but a Python script “cpu/export.py” should be run to copy all design files to your project folder.

Usage: export.py <destination-folder>

Copies all core A-Z80 Verilog files to a destination folder of your choice.

This example shows how to run it to copy files to your project folder:

python.exe export.py c:\projects\board\cpu

Copying control/clk_delay.v

Copying control/decode_state.v

Copying toplevel/coremodules.vh

Copying toplevel/globals.vh

Done copying 49 files.

All necessary A-Z80 CPU files are copied to c:\projects\board\cpu

Add all Verilog files (*.v) to your project and ensure that Verilog include

files (*.vh) are on the include path.

Use z80_top_direct_n.v as your top-level interface file.

Note for the users of Lattice FPGA toolset: instead of data_pins.v, manually

copy and use data_pins_lattice.v file instead.

Several fully working sample implementations (basic host and zxspectrum) should provide good starting point.

# Interface

The top-level file “z80_top_direct_n.v” exports the following interface:

module z80_top_direct_n(

output wire nM1,

output wire nMREQ,

output wire nIORQ,

output wire nRD,

output wire nWR,

output wire nRFSH,

output wire nHALT,

output wire nBUSACK,

input wire nWAIT,

input wire nINT,

input wire nNMI,

input wire nRESET,

input wire nBUSRQ,

input wire CLK,

output wire [15:0] A,

inout wire [7:0] D

);

This interface pinout is 100% identical to the Zilog Z80 package pins. It implements Z80 bus timings and features tri state signals and buses. (While admittedly not optimal for an FPGA implementation, it perfectly mimics the actual Z80 silicon which was one of the goals of this project).

# Example Implementations

Several working implementations are included. They are all located in the “host” directory and use Altera DE1 and Xilinx Nexys3 development boards.

Warning: The synthesis and fMax numbers as shown might vary depending on your tool version, applied timing constraints and the exact configuration.

## Simple host

“basic host” project has two targets: “basic_de1” can be used on a Terasic DE1 board and “basic_nexys3” can be used on a Digilent Nexys 3 board. Each contains the A-Z80 CPU, 16 KB RAM configured as single port RAM and a unidirectional implementation of the UART for the text output. Each target project also includes a corresponding verification ModelSim configuration (for Altera) or an ISim test bench (for Xilinx).

File | Description
host\basic_de1\basic_de1.qpf | Quartus project file
host\...\simulation\modelsim\test_host.mpf | ModelSim project file for simulation
host\basic_de1\basic_de1_fpga.sv | Top-level board source file for FPGA implementation
host\basic_de1\basic_de1_ModelSim.sv | Top-level board source file for ModelSim board model
host\basic_de1\test_host.sv | ModelSim test bench for the simulation

File | Description
host\basic_nexys3\basic_nexys3.xise | Xilinx ISE project file
host\basic_nexys3\basic_nexys3_fpga. v | Top-level board source file for FPGA implementation
host\basic_nexys3\test_host.v | Test bench for the iSim simulation tool

This host board can load and run any Z80 executable (for example, one of those in “tools\zmac” directory). Programs can print to UART and, on a physical DE1 or Nexys3 boards, the text is seen through the attached serial terminal.

When run within a simulation environment, the text is written to a ModelSim or ISim output windows.

The following image shows the output of “tools\zmac\hello_world.asm” being captured through a serial port:

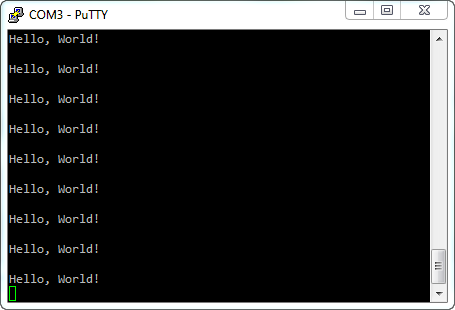
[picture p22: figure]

Image 2: "Hello, World"

Synthesis result of this simple design on an Altera DE1 board shows only 11% of the total LE resources used:

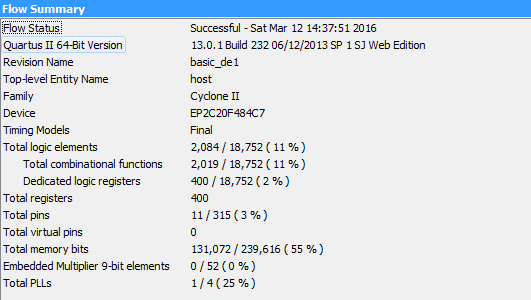
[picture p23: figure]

The CPU CLK is derived from the pll_clk and the effective Slow Model fMax for this compilation is 18.89 MHz.

Xilinx ISE tools synthesize the design using about 19% of Nexys3 device slice resources:

Selected Device: 6slx16csg324-2

Slice Logic Utilization:

Number of Slice Registers: 396 out of 18224 2%

Number of Slice LUTs: 1819 out of 9112 19%

Number used as Logic: 1819 out of 9112 19%

Slice Logic Distribution:

Number of LUT Flip Flop pairs used: 2113

Number with an unused Flip Flop: 1717 out of 2113 81%

Number with an unused LUT: 294 out of 2113 13%

Number of fully used LUT-FF pairs: 102 out of 2113 4%

Number of unique control sets: 70

IO Utilization:

Number of IOs: 37

Number of bonded IOBs: 36 out of 232 15%

Specific Feature Utilization:

Number of Block RAM/FIFO: 8 out of 32 25%

Number using Block RAM only: 8

Number of BUFG/BUFGCTRLs: 3 out of 16 18%

## Sinclair ZX Spectrum

This project implements a Sinclair ZX Spectrum 48K computer on an Altera DE1 board. See directory “host\zxspectrum_de1” containing a Quartus project file.

Directory “host\zxspectrum\ula” contains drivers for a PS/2 keyboard, video (using a VGA port), sound, RAM memory and clocks. Those were kinds of functions handled by Spectrum’s custom Ferranti ULA chip.

There are 2 system ROM images included in the “host\zxspectrum\rom” directory – the original ZX Spectrum ROM and an improved, so-called “Gosh Wonderful” ROM – merged into a single image which is to be flashed into the DE1’s flash memory starting at the address 0. Use a flash tool that came with your DE1 board software to flash this data.

The following table shows the function of buttons and switches. When a switch is activated, a red LED above it glows.

Button and Switch | Description
KEY0 | Reset
KEY1 | Issues NMI
SW0 | Selects “Gosh Wonderful ROM” image versus the original ROM image
SW1 | Disables interrupts
SW2 | Turbo mode (3.5 MHz x 2 = 7.0 MHz)

Function of green LEDs is to show:

GREEN LED | Description
LEDG0-LEDG4 | Kempston joystick UP, DOWN, LEFT, RIGHT, FIRE is pressed
LEDG5 | A key is pressed
LEDG6 | When blinking, a speaker or line-in is active

If you decide to try this design on your DE1 board and then want to play actual games, connect an Android device earphone jack out to DE1’s LINE-IN and use one of several apps to “play” a game into the device. For example, Baltazar Studio’s PlayZX was written for that purpose only:

https://play.google.com/store/apps/details?id=com.baltazarstudios.playzxtapes

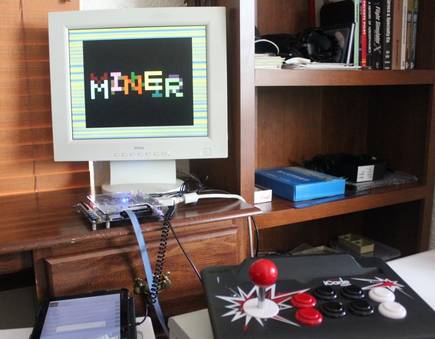
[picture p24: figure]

Image 3 : Sinclair ZX Spectrum on Altera DE1

Image 3 shows a game “Manic Miner” being loaded through the audio line-in connector into the FPGA board visible in the middle and a Kempston compatible joystick in the foreground.

This is a synthesis result of a ZX Spectrum host design on an Altera DE1 board:

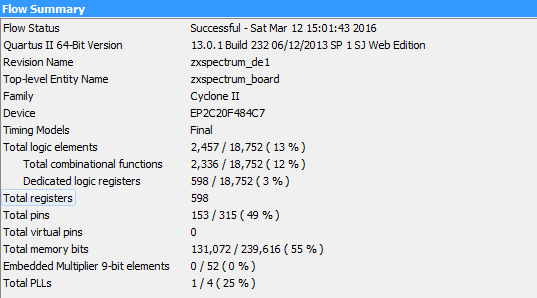
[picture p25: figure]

# Advanced Topics

## Modifying the A-Z80 CPU Core

If you want to make a change to any instruction’s timing or a sequence of micro-operations, modify “cpu\control\Timings.xlsm” file. This is an Excel spreadsheet that contains timing tables for each group of instructions as decoded by opcode PLA and sequencer state. Vertical columns contain operations on specific CPU blocks. Instruction groups are listed by the M and T-clocks providing the exact timing for each set of operations.

Micro-operations are represented by short tokens (for example, “PC” or “mr”) which are defined in the file “cpu\control\timing_macros.i”. Every token is translated into one or more discrete control signals causing a desired operation. All such control signals start with the key “ctl_”.

After changing the timing spreadsheet, export it into a TAB-delimited file. If you are using MS Excel, the simplest way is to use a macro that is already embedded into the spreadsheet (MS Excel can only save TAB-delimited files as TXT files. Using this macro is faster.) Click on the “Developer” menu and then on “Macros” icon:

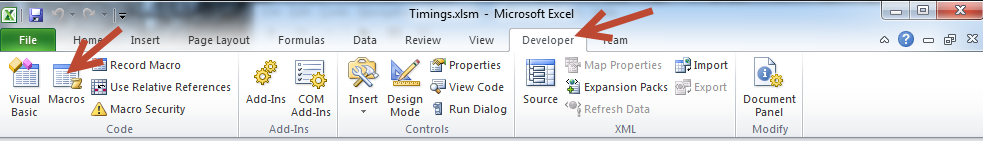
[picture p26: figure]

Running “CopyToCSV” macro will replace the existing CSV file with your modified version:

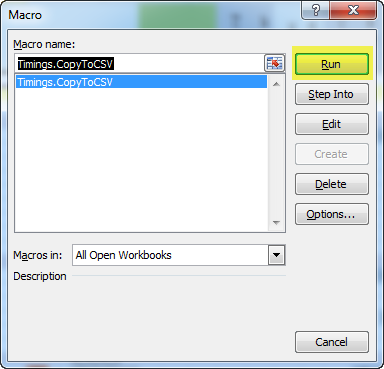
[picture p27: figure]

If you use LibreOffice Calc instead of MS Excel, export the spreadsheet using “File” -> “Save a Copy…”, select “Text CSV (*.csv)” from the file type dropdown list. Check “Edit filter settings”:

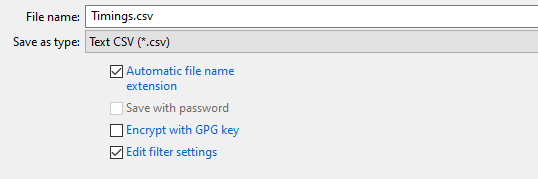
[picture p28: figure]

Click on “Save”, accepting to replace the existing “Timings.csv” file. Select “{Tab}” as the Field delimiter and click on “OK” to save the file.

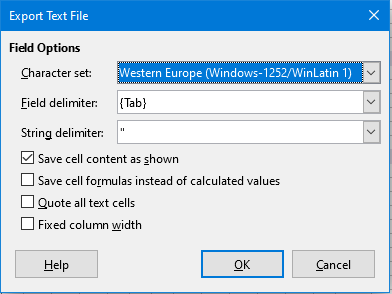
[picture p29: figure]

The output CSV file written by LibreOffice will slightly differ from the one written by MS Excel, but those differences are benign and both variations are functionally valid.

The next step is to create a Verilog file based on those timings by running a python script “cpu\control\genmatrix.py”. That script reads in the CSV file containing timing tables and generates “exec_matrix.vh” that implements the actual Verilog code to control the timings.

Although Altera Quartus synthesis tool can use that file to compile a working design, Xilinx synthesis tool is not able to handle its complexity, so for Xilinx devices an additional step is needed which takes that file and converts it to a format their tools are able to handle. Run “cpu\control\gencompile.py” to generate “exec_matrix_compiled.vh” file that defines the same set of combinatorial operations but in a sum-of-product terms.

All Python scripts in this project can be run in-place without the need to specify any arguments.

You can either run them from a command line, or you can simply double-click on them in a Windows environment assuming that your shell is configured to properly handle “.py” extensions.

On the other hand, if you change any schematic file, where your change adds or removes a global input or output signal, you need to run these three Python scripts to recreate various lists of global includes:

“cpu\control\gencoremodules.py” – generates instantiation file for all modules:

- “core.vh” contains all instantiated CPU modules.

“cpu\control\genref.py” – generates global include files using all exported module signals:

- “exec_module.vh” contains input/output definitions to be included in the module def.
- “exec_zero.vh” contains Verilog code to set all input wires to zero.

“cpu\toplevel\genglobals.py” – generates a list of global wire defines:

- “globals.vh” contains Verilog code that defines all global signal wires.

Quartus project files (*.qpf, *.qsf) in “cpu\alu”, “cpu\bus”, “cpu\control” and “cpu\registers” directories are non-functional and just conveniently hold sets of files together within a conceptually modular overall design. Quartus project in the “cpu\toplevel” directory only contains a top-level schematic diagram, also not functional. Hence, they are only convenient containers to hold files.

When modifying a schematic file (and most of the A-Z80 blocks are designed at the schematic level), open the corresponding Quartus container project (for example, when modifying a schematic in the ALU block, open “cpu\alu\test_alu.qpf”). Change the schematics, compile it (to make sure it has no errors) and then export it to both the Verilog equivalent and a symbol file, as shown below:

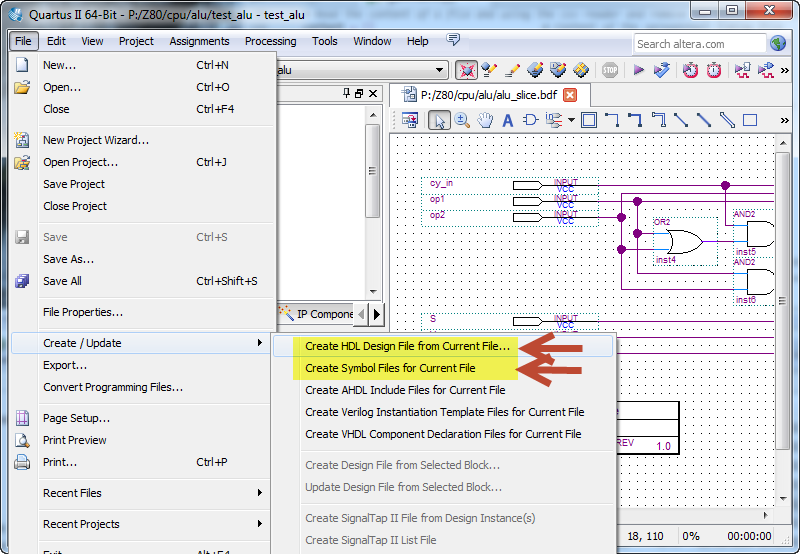
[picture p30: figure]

Verilog versions are used as the final target files which compile along with the rest of the A-Z80 core files. Symbol files are (at the moment) optional, but could be used in the future to create a fully working schematic top-level (TBD).

## File Generators

This section describes Python scripts and processes that generate various files. You should never edit or change generated files since they will be overwritten the next time scripts are run. Many scripts have additional options, but since the defaults are meaningful, the scripts can be run in a very simple way (for example, by simply double-clicking on them).

See each individual script source for more information.

### Building the CPU

Process: | cpu/control/Timings.xlsm
Generates file: | cpu/control/Timings.csv
Uses files: | -

This is a MS Excel spreadsheet that defines a matrix of timings vs. operations for each group of instructions. The spreadsheet contains an embedded macro that exports that data in a suitable format; go to the Developer tab, and in the Code group, click on Macros. Run a macro “Timings.CopyToCSV”.

Process: | cpu/control/genmatrix.py
Generates file: | cpu/control/exec_matrix.vh
Uses files: | Timings.csv, timing_macros.i

This script reads the A-Z80 instruction timing data from a (generated) spreadsheet text file and creates a Verilog include file which defines the control block execution logic matrix. Token keywords in the timing spreadsheet are substituted using a list of keys stored in the timing macros file.

Process: | cpu/control/gencompile.py
Generates file: | cpu/control/exec_matrix_compiles.vh, temp_wires.vh
Uses files: | cpu/control/exec_matrix.vh

This script reads the exec matrix file and compiles it into an alternate format that can be used with Xilinx tools.

Process: | cpu/control/genref.py
Generates file: | cpu/control/exec_module.vh, exec_zero.vh
Uses files: | top_level_files.txt + list of files in that file

This script reads a list of files from the “top_level_files.txt” and processes each file to extract selected names of wires defined in their respective modules to be used to easily define and initialize them.

Process: | cpu/toplevel/gencoremodules.py
Generates file: | cpu/toplevel/coremodules.vh
Uses files: | top_level_files.txt + list of files in that file

This script reads and parses all top-level modules and generates a core block file containing instantiation of these modules in Verilog format. The generated file in included by core.vh.

Process: | cpu/toplevel/genglobals.py
Generates file: | cpu/toplevel/globals.vh
Uses files: | top_level_files.txt + list of files in that file

This script reads a list of files from the “top_level_files.txt” and processes each file to extract selected names of wires defined in their respective modules to be used as global wires.

Process: | tools/z80_pla_checker.exe
Generates file: | Verilog PLA decode module
Uses files: | PLA and opcode defines from resource folder

This executable program reads a PLA table in a simple format (reverse-engineered from a picture of a die) and generates a Verilog PLA decode module.

### Verification/Tests

Process: | cpu/toplevel/genfuse.py
Generates file: | cpu/toplevel/test_fuse.vh
Uses files: | fuse/tests.in, tests.expected, regress.in, regress.expected

This script creates a Fuse test in Verilog from several test description files.

Process: | tools/zmac/make_fpga.bat, make_modelsim.bat
Generates file: | Compiled HEX files
Uses files: | Z80 assembler source files

These DOS batch files compile and create HEX files from any Z80 assembler source files dropped onto it. They speed up running and testing of Z80 programs.

BaltazarStudios.comPage 29

A-Z80 CPU User’s Guide

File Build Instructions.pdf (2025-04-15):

# Build Instructions - Game Gear

Software Setup
1. Download the Raspberry Pi Image from here (https://drive.google.com/drive/folders/1cTOPLiqQtfveVBptVOEDtFShPZntb5K-?usp=drive_link) and ash it onto a Micro SD card using Balena Etcher (https://etcher.balena.io/) before inserting it into the Raspberry Pi.

Hardware Assembly

### 1. Solder the header pins onto the Pi and PCB. Refer to the Bill of Materials

as well as the images below of the PCBs to determine where to attach the header pins.
a. The header pins for the Pi go on the main GPIO header found on the board.
b. The header pins for the PCB go in the spots labeled “Conn_***_Pin” on the PCB diagrams below.

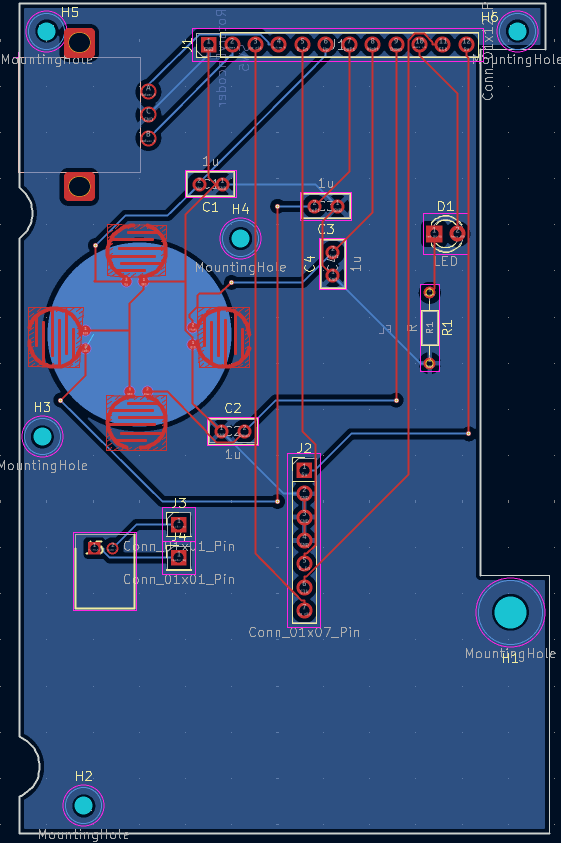
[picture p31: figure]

Figure 1: Left PCB.

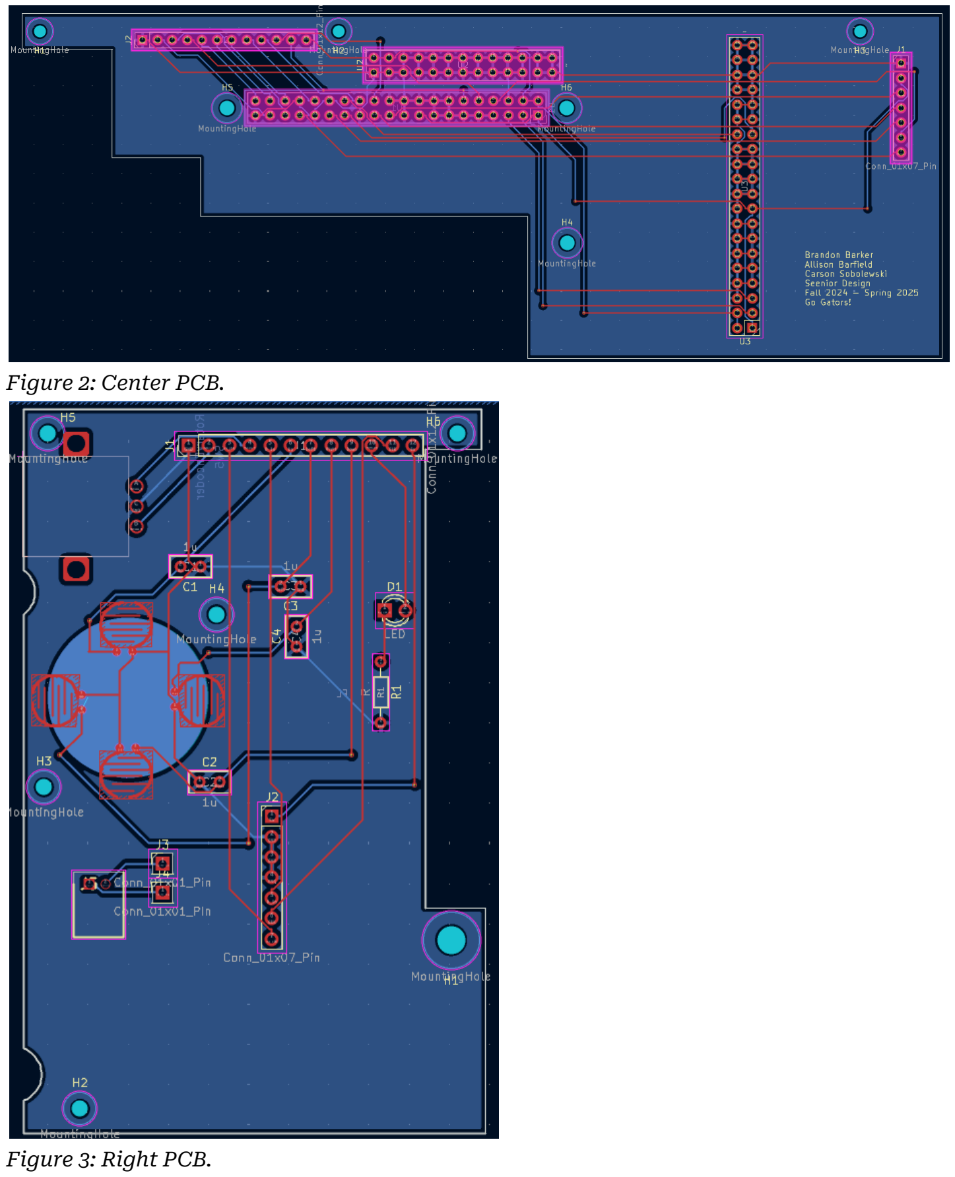
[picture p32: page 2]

Figure 2: Center PCB.

Figure 3: Right PCB.

### 2. Place and solder all components to the PCB according to the Bill of

Materials. Most components are labeled with their corresponding identiers on the PCB, indicating where they go. For all others, refer to the above images or the PCB design les on GitHub directly.

### 3. Solder the power switch to one end of wires and solder the other end to

the J5 header on the PiJuice board as shown below.

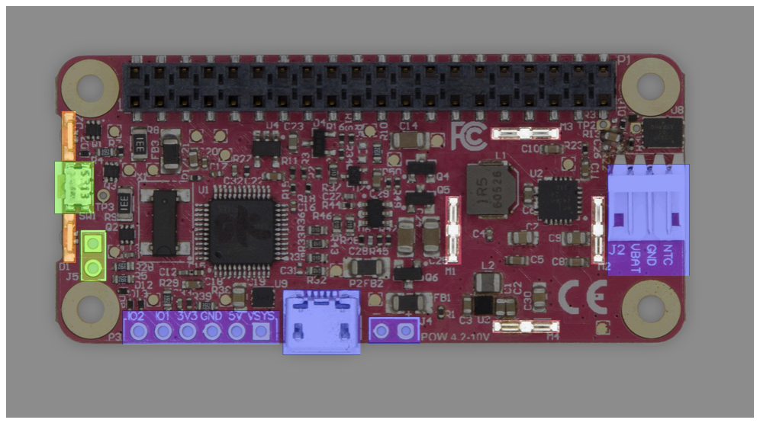
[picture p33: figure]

Figure 4: Wires for the power switch should be soldered to J5, highlighted in green on the left.

4. Attach the PCBs to the case using the mounting holes shown below.

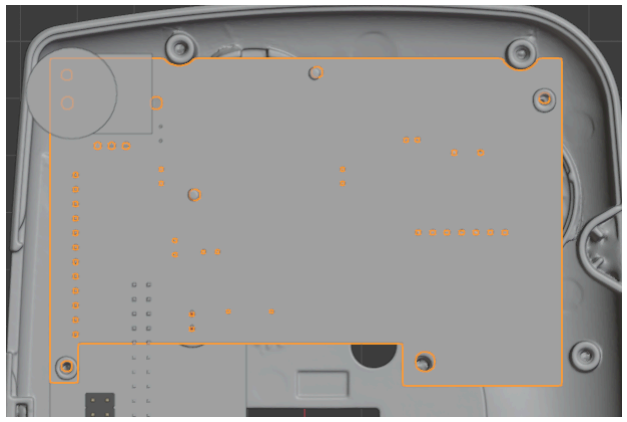
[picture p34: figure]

Figure 5: PCB holes align with mounting holes on the front of the case.

5. Attach the screen via an HDMI ribbon cable to the Pi’s HDMI port.

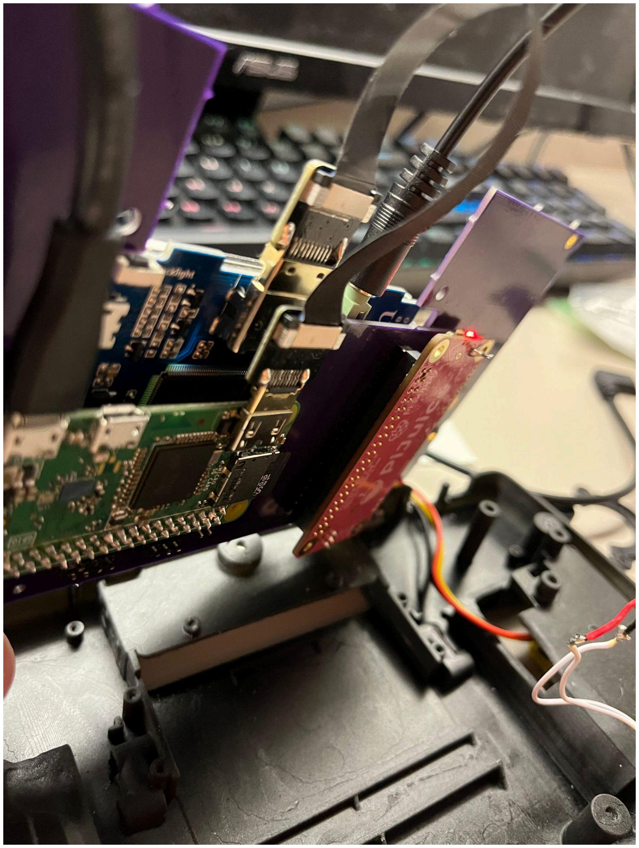
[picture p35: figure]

Figure 6: HDMI ribbon cable connection.

### 6. Solder the speaker wires to the audio jack cable and plug it into the

screen.

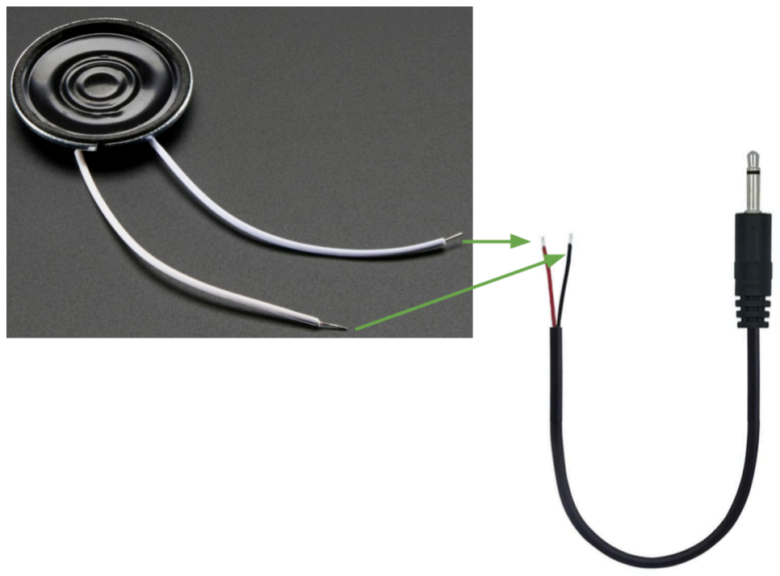
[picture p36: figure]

Figure 7: Diagram for soldering the speaker to the two-wire aux adapter, allowing easy connection to the HDMI screen.

### 7. Connect the cartridge slot to the JoeyGG reader and attach via a USB-C

cable.

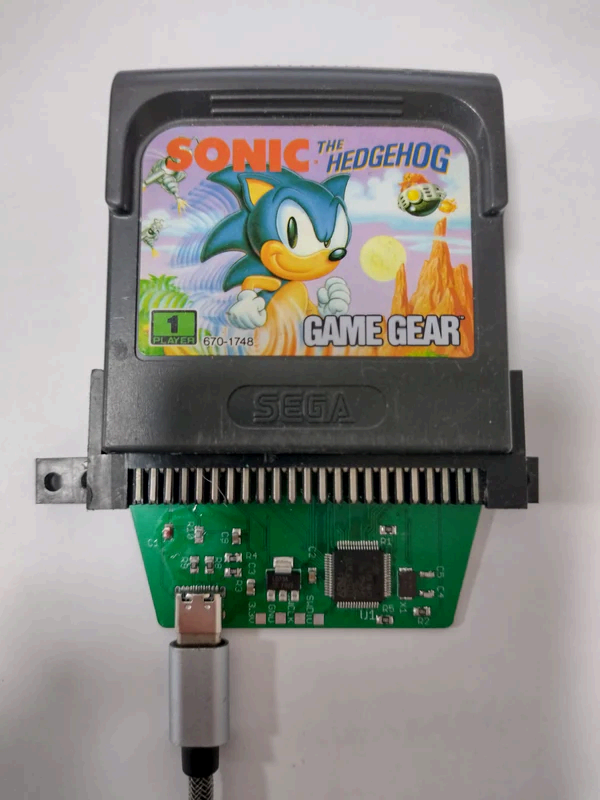
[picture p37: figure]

Figure 8: Cartridge slot soldered to JoeyGG reader, running a “Sonic the Hedgehog” cartridge.

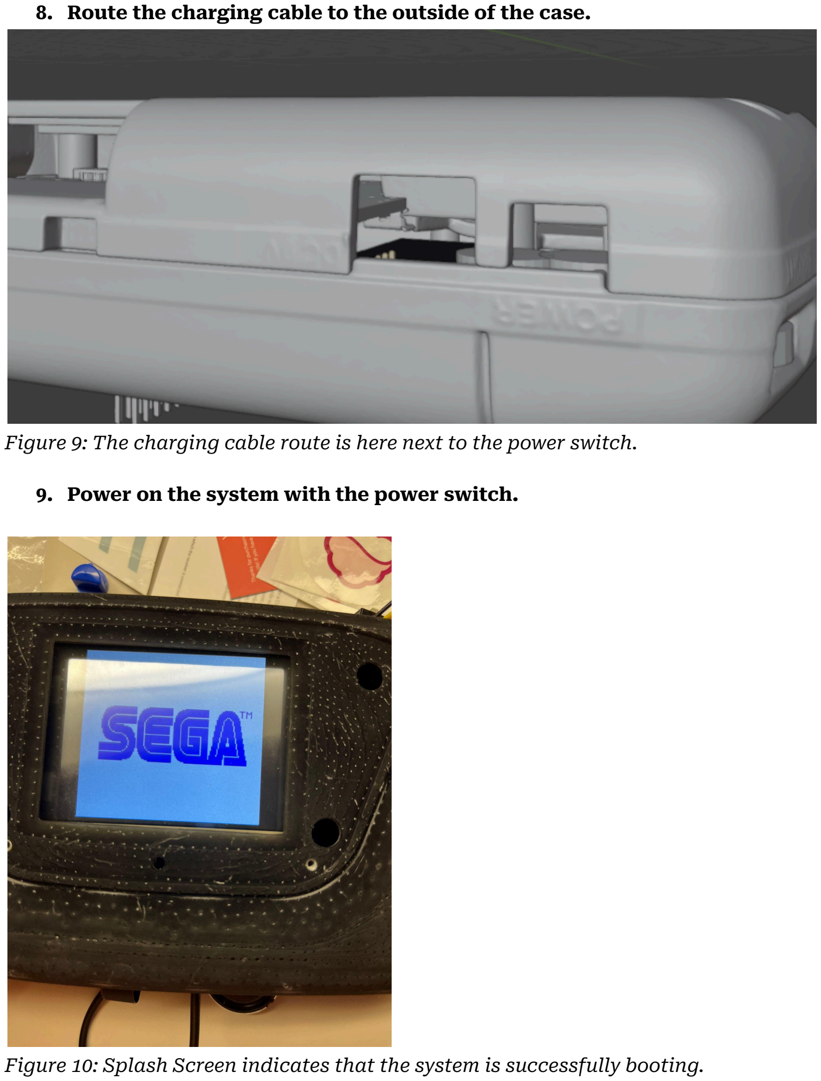
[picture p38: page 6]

8. Route the charging cable to the outside of the case.

Figure 9: The charging cable route is here next to the power switch.

9. Power on the system with the power switch.

Figure 10: Splash Screen indicates that the system is successfully booting.

10. Plug in a cartridge to test.

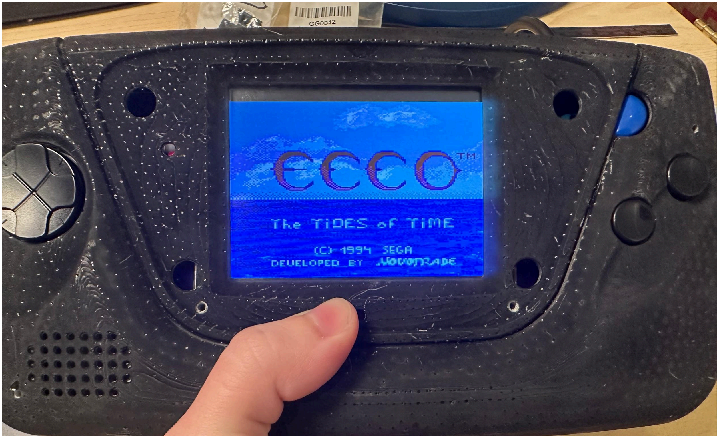
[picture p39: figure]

Figure 11: The cartridge will automatically boot on insertion.

### 11. Close the case by attaching the back shell and screwing it to the front

shell.

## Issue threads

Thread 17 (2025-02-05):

PCB

allisonmb, 2025-02-05:
Design a PCB to fit into a game gear case which connects all hardware needed for the game gear

Closed 2025-03-07.

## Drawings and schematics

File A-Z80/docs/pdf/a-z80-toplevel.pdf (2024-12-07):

## CONTROL UNIT

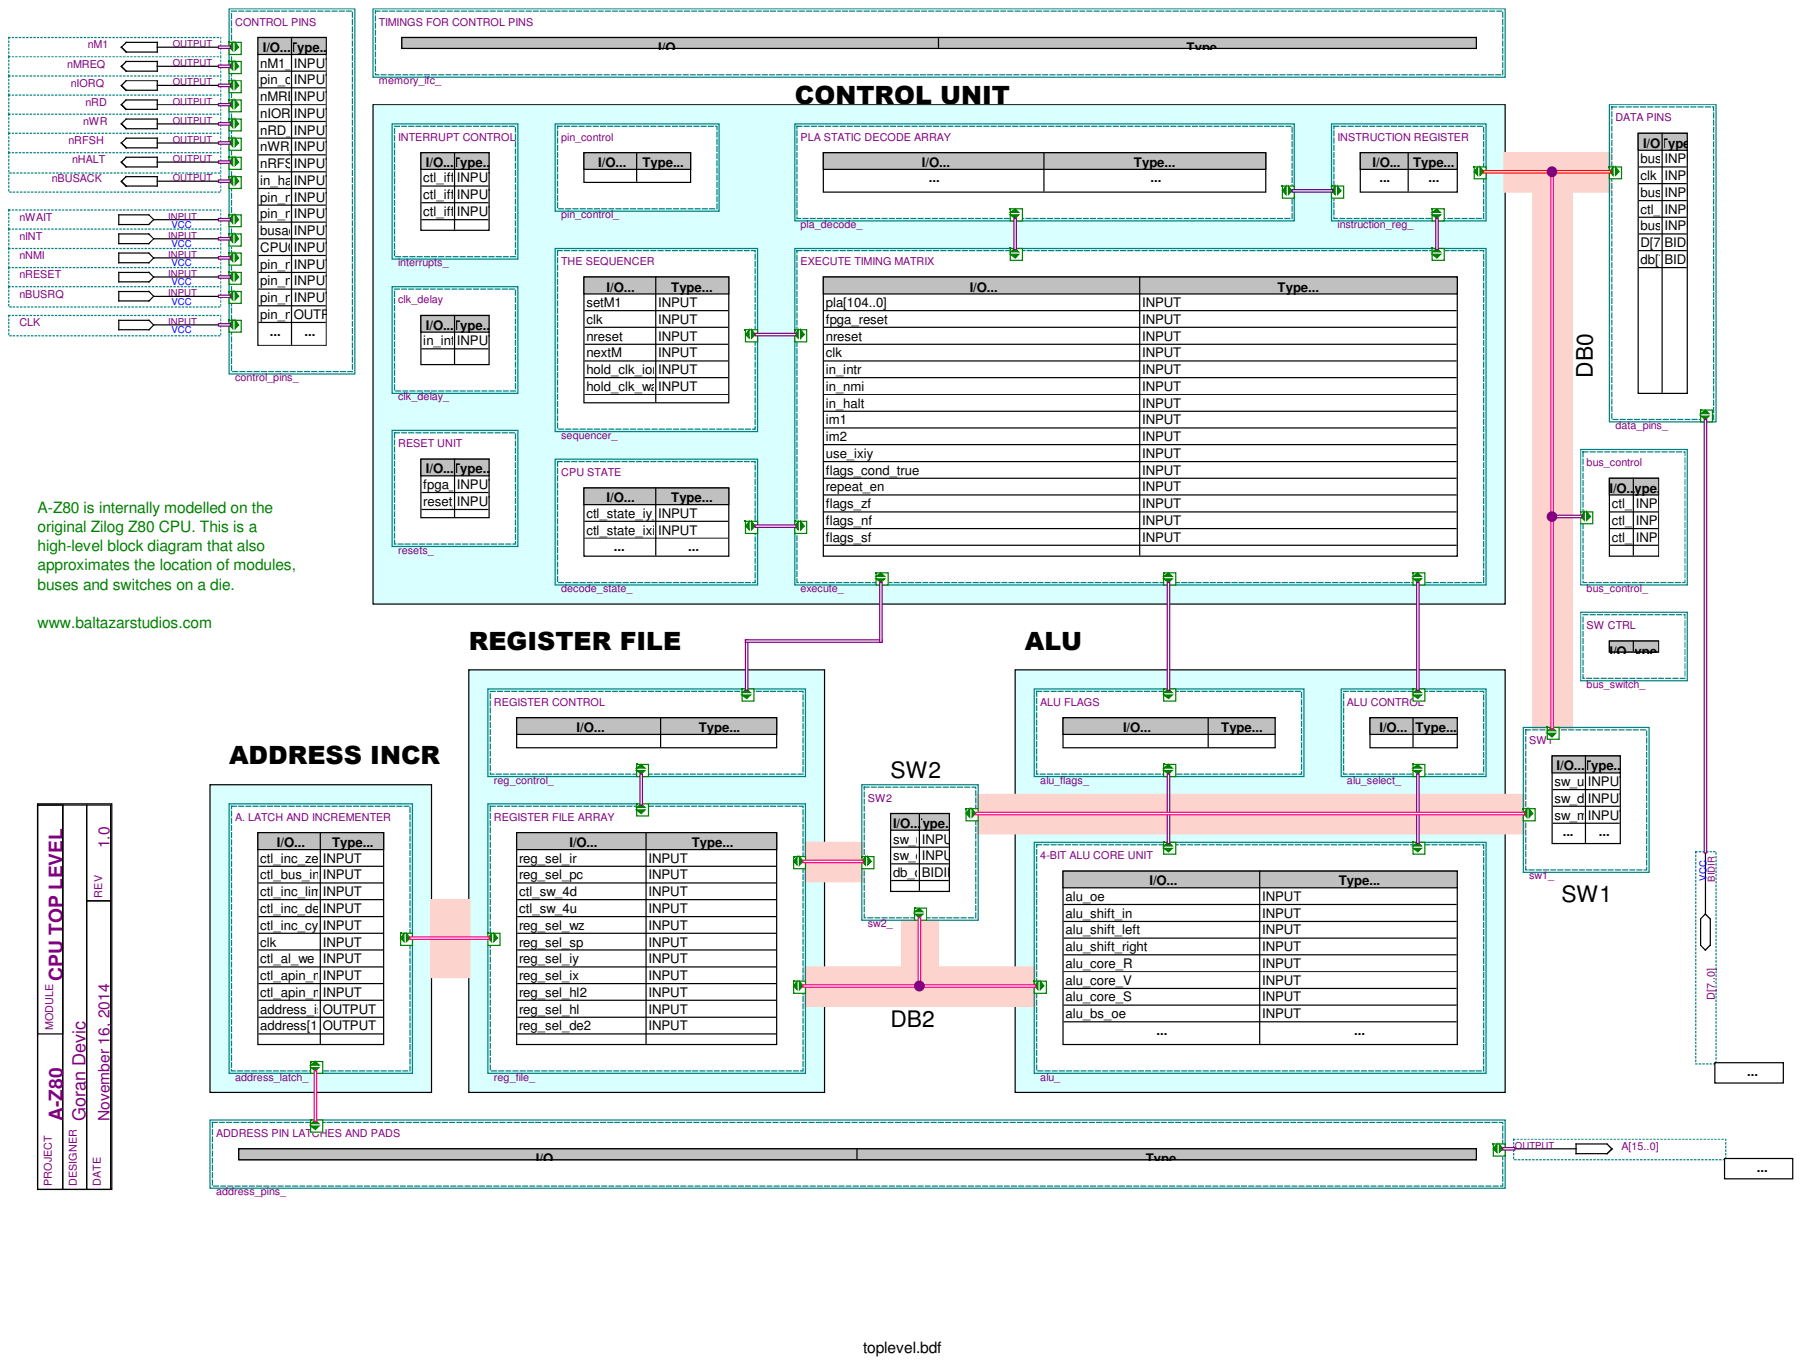
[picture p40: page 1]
toplevel.bdf; REGISTER FILE; ALU; ADDRESS INCR; VCC nWAIT; INPUT; VCC; nINT; nNMI; VCC nRESET; VCC nBUSRQ; VCC CLK; OUTPUT; nMREQ; nIORQ; nRD; nWR; nRFSH; nBUSACK; nHALT; pin_control; pin_control_; Type...; clk_delay; clk_delay_; in_intrINPUT; I/O...Type...; bus_control; bus_control_; ctl_bus_db_oe INPUT ctl_bus_zero_oe INPUT ctl_bus_ff_oe INPUT; I/O... Type...; sw_up_en INPUT sw_down_en INPUT sw_mask543_en INPUT; sw_up_en INPUT sw_down_en INPUT db_down[7..0] BIDIR; alu_; alu_oe; alu_shift_in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

TIMINGS FOR CONTROL PINS

I/O...Type...
nM1_out INPUT
pin_control_oe INPUT
nMREQ_out INPUT

PLA STATIC DECODE ARRAY

EXECUTE TIMING MATRIX

clk | INPUT
in_intr | INPUT
in_nmi | INPUT

A-Z80 is internally modelled on the
original Zilog Z80 CPU. This is a
high-level block diagram that also
approximates the location of modules,
buses and switches on a die.

www.baltazarstudios.com

A. LATCH AND INCREMENTER

REGISTER FILE ARRAY

MODULECPU TOP LEVEL

4-BIT ALU CORE UNIT

DESIGNER Goran Devic

ADDRESS PIN LATCHES AND PADS

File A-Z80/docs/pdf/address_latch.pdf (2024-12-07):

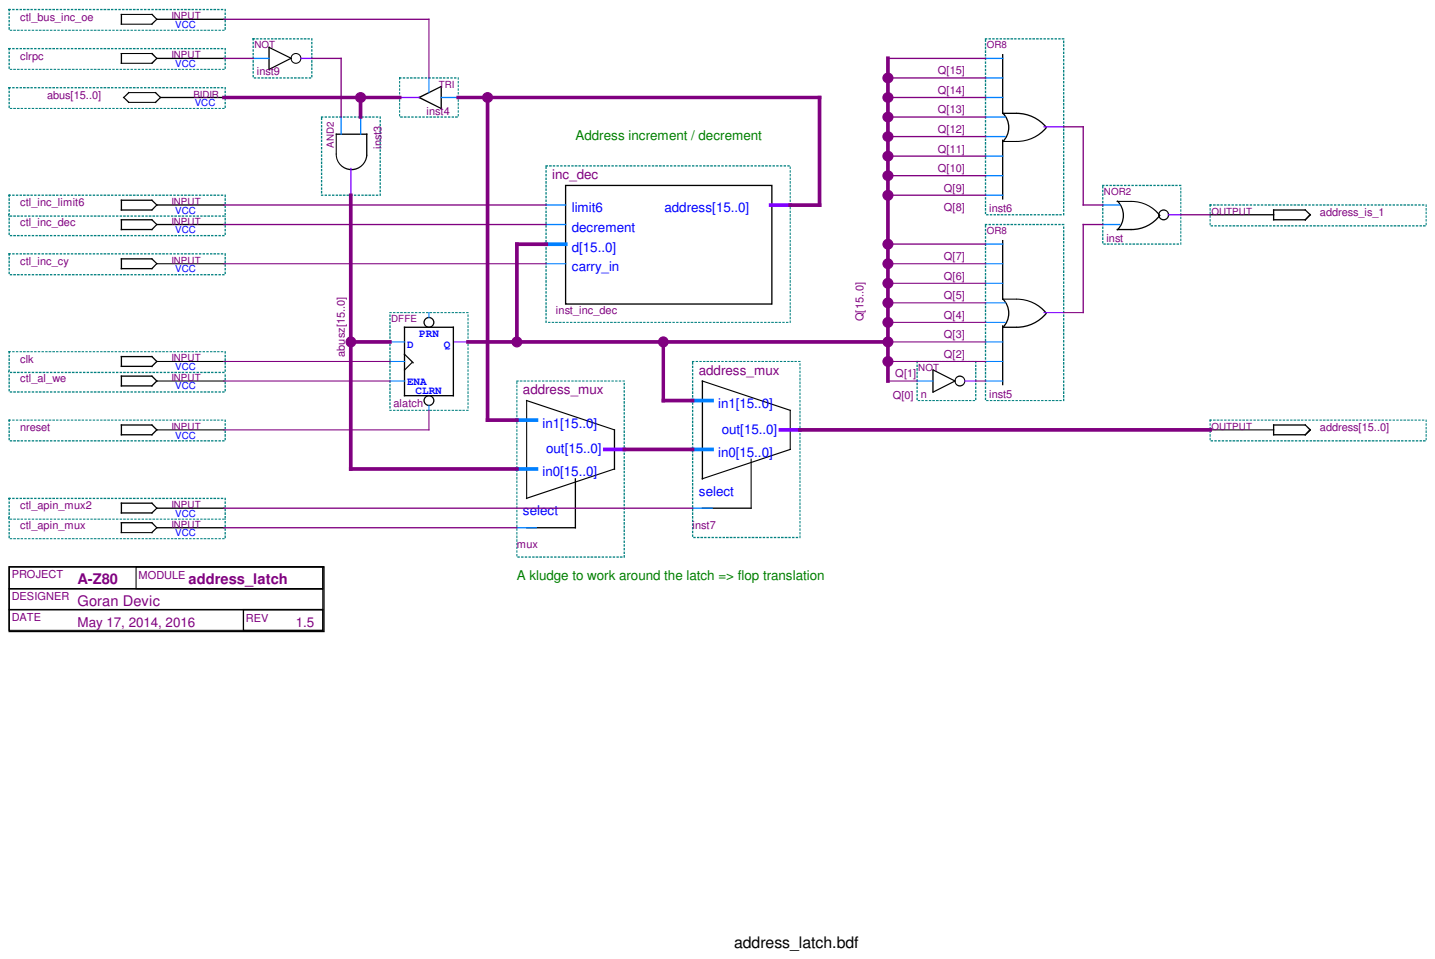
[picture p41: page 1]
address_latch.bdf; abusz[15..0]; VCC ctl_inc_cy; INPUT; VCC ctl_inc_dec; VCC ctl_al_we; VCC ctl_inc_limit6; VCC ctl_bus_inc_oe; VCC clk; VCC ctl_apin_mux; VCC ctl_apin_mux2; VCC clrpc; VCC nreset; OUTPUT; address[15..0]; address_is_1; VCC abus[15..0]; BIDIR; TRI; inst4; limit6 decrement d[15..0] carry_in; inc_dec; inst_inc_dec; PRN; CLRN; ENA; DFFE; alatch; inst5; inst6; NOT; NOR2; inst; select; out[15..0]; address_mux; mux; inst7; AND2; inst3; inst9; DATE; May 17, 2014, 2016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

Address increment / decrement

DESIGNER Goran Devic

A kludge to work around the latch => flop translation

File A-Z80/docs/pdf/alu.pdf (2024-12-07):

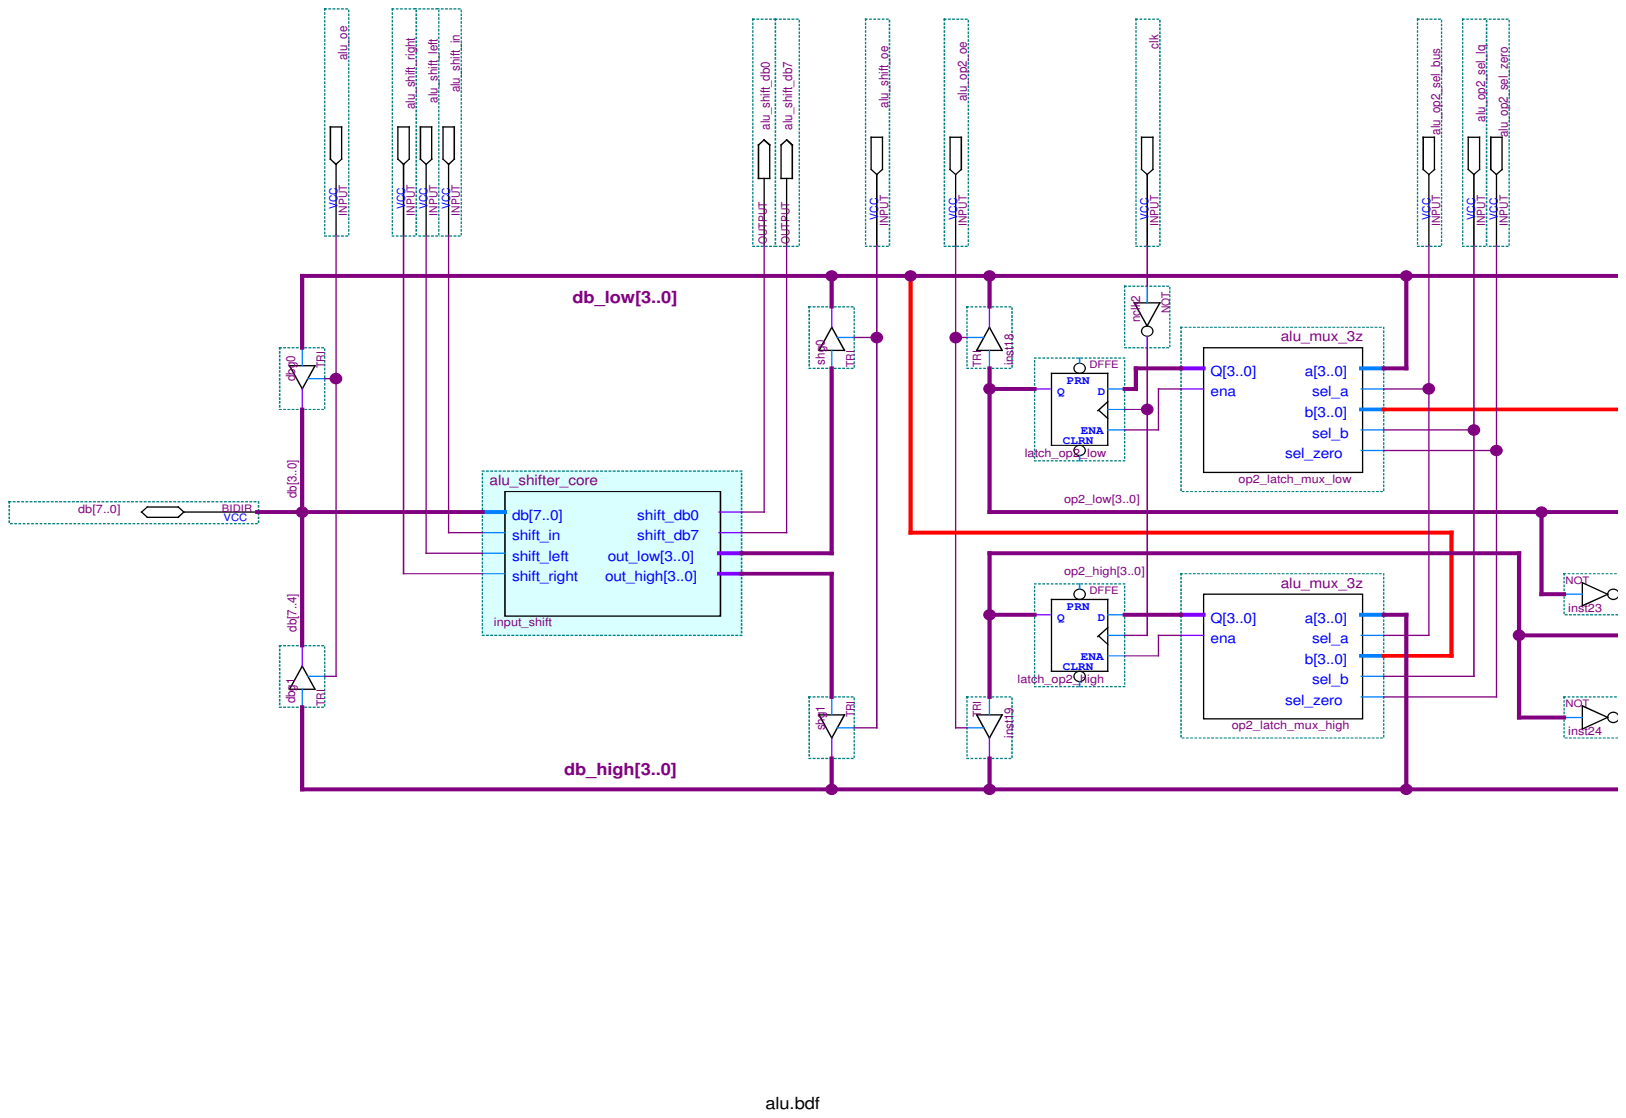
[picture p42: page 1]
alu.bdf; db_low[3..0]; db_high[3..0]; op2_high[3..0]; op2_low[3..0]; VCC; alu_oe INPUT; alu_shift_oe INPUT; alu_op2_oe INPUT; alu_op2_sel_zero INPUT; alu_op2_sel_bus INPUT; alu_op2_sel_lq INPUT; alu_shift_in INPUT; alu_shift_left INPUT; alu_shift_right INPUT; clk INPUT; alu_shift_db0 OUTPUT; alu_shift_db7 OUTPUT; VCC db[7..0]; BIDIR; NOT; inst23; inst24; TRI; inst18; inst19; shg0; TRI TRI; shg1; dbg0 dbg1; shift_in; shift_left; shift_right; shift_db0; shift_db7; out_low[3..0]; out_high[3..0]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

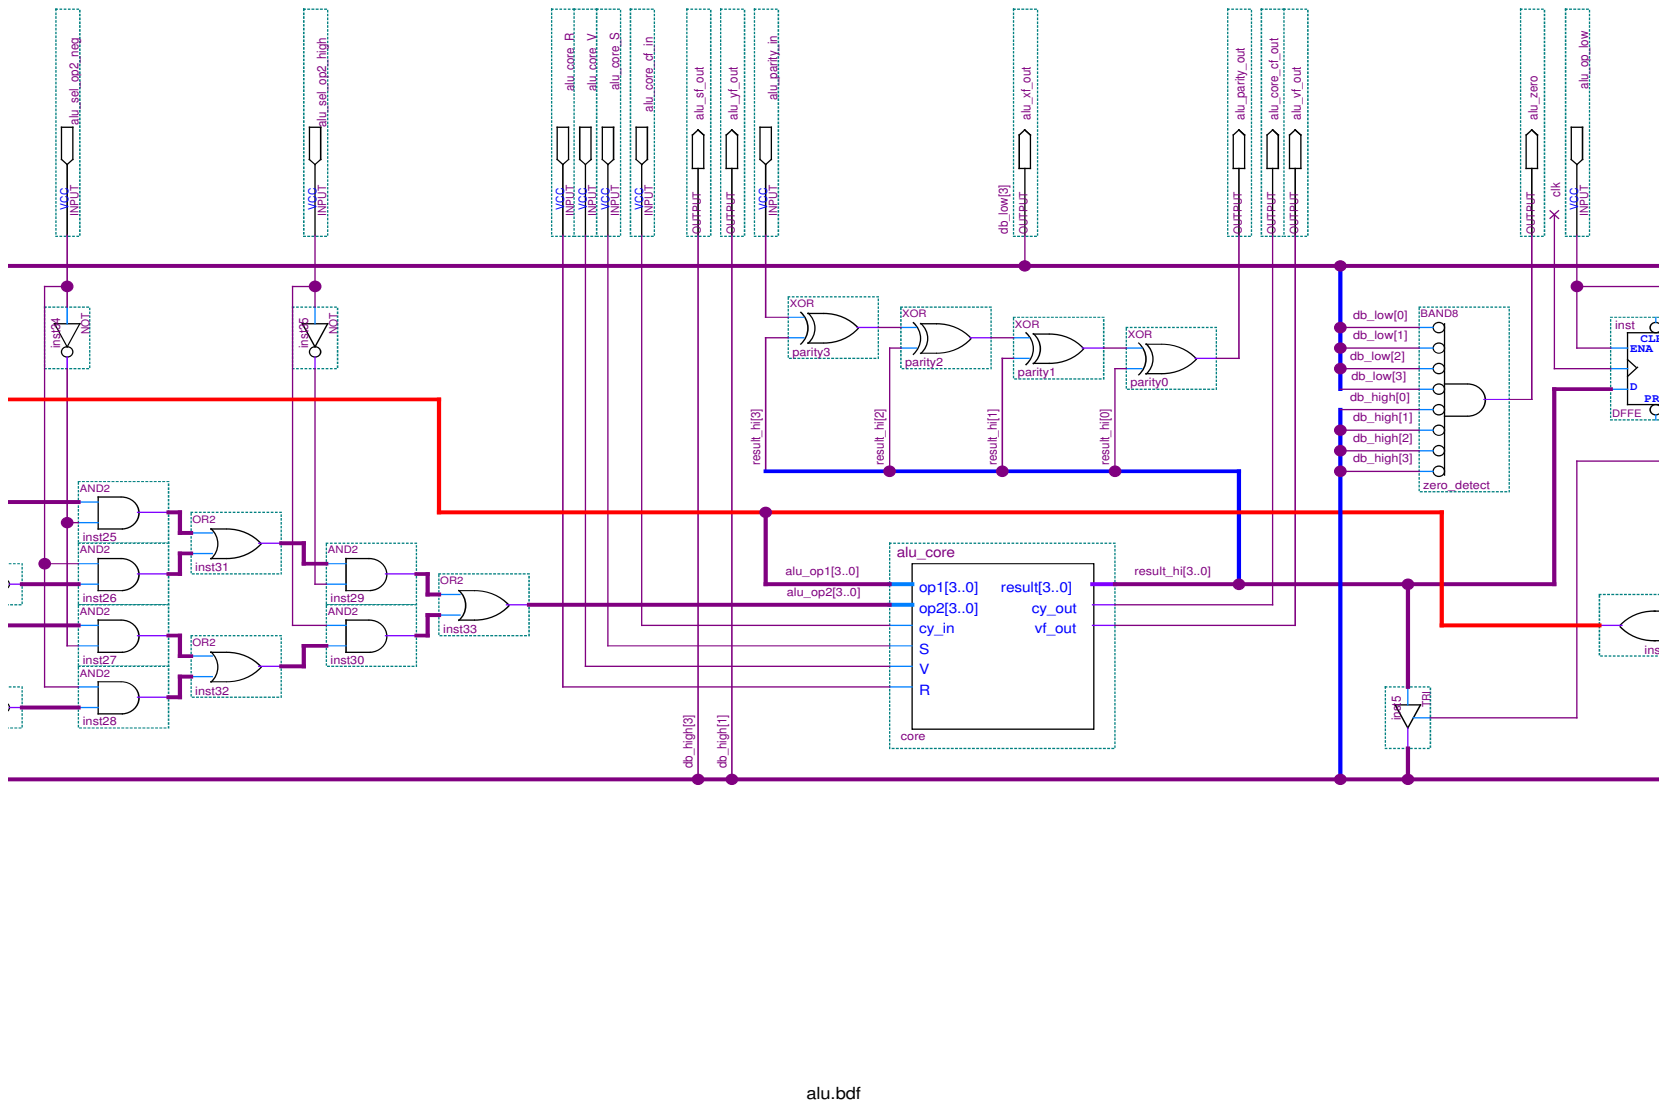
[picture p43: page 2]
db_high[3]; db_high[1]; result_hi[3]; result_hi[2]; result_hi[1]; result_hi[0]; db_low[3]; alu_op1[3..0]; result_hi[3..0]; alu_op2[3..0]; db_low[2]; db_low[1]; db_high[0]; db_high[2]; db_low[0]; clk; VCC; alu_core_R INPUT; alu_core_V INPUT; alu_core_S INPUT; alu_parity_in INPUT; alu_core_cf_in INPUT; alu_op_low INPUT; alu_sel_op2_neg INPUT; alu_sel_op2_high INPUT; alu_zero OUTPUT; alu_parity_out OUTPUT; alu_core_cf_out OUTPUT; alu_sf_out OUTPUT; alu_yf_out OUTPUT; alu_xf_out OUTPUT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

# DESIGNER Goran Devic

DATE | May 18, 2014 | REV | 1.4

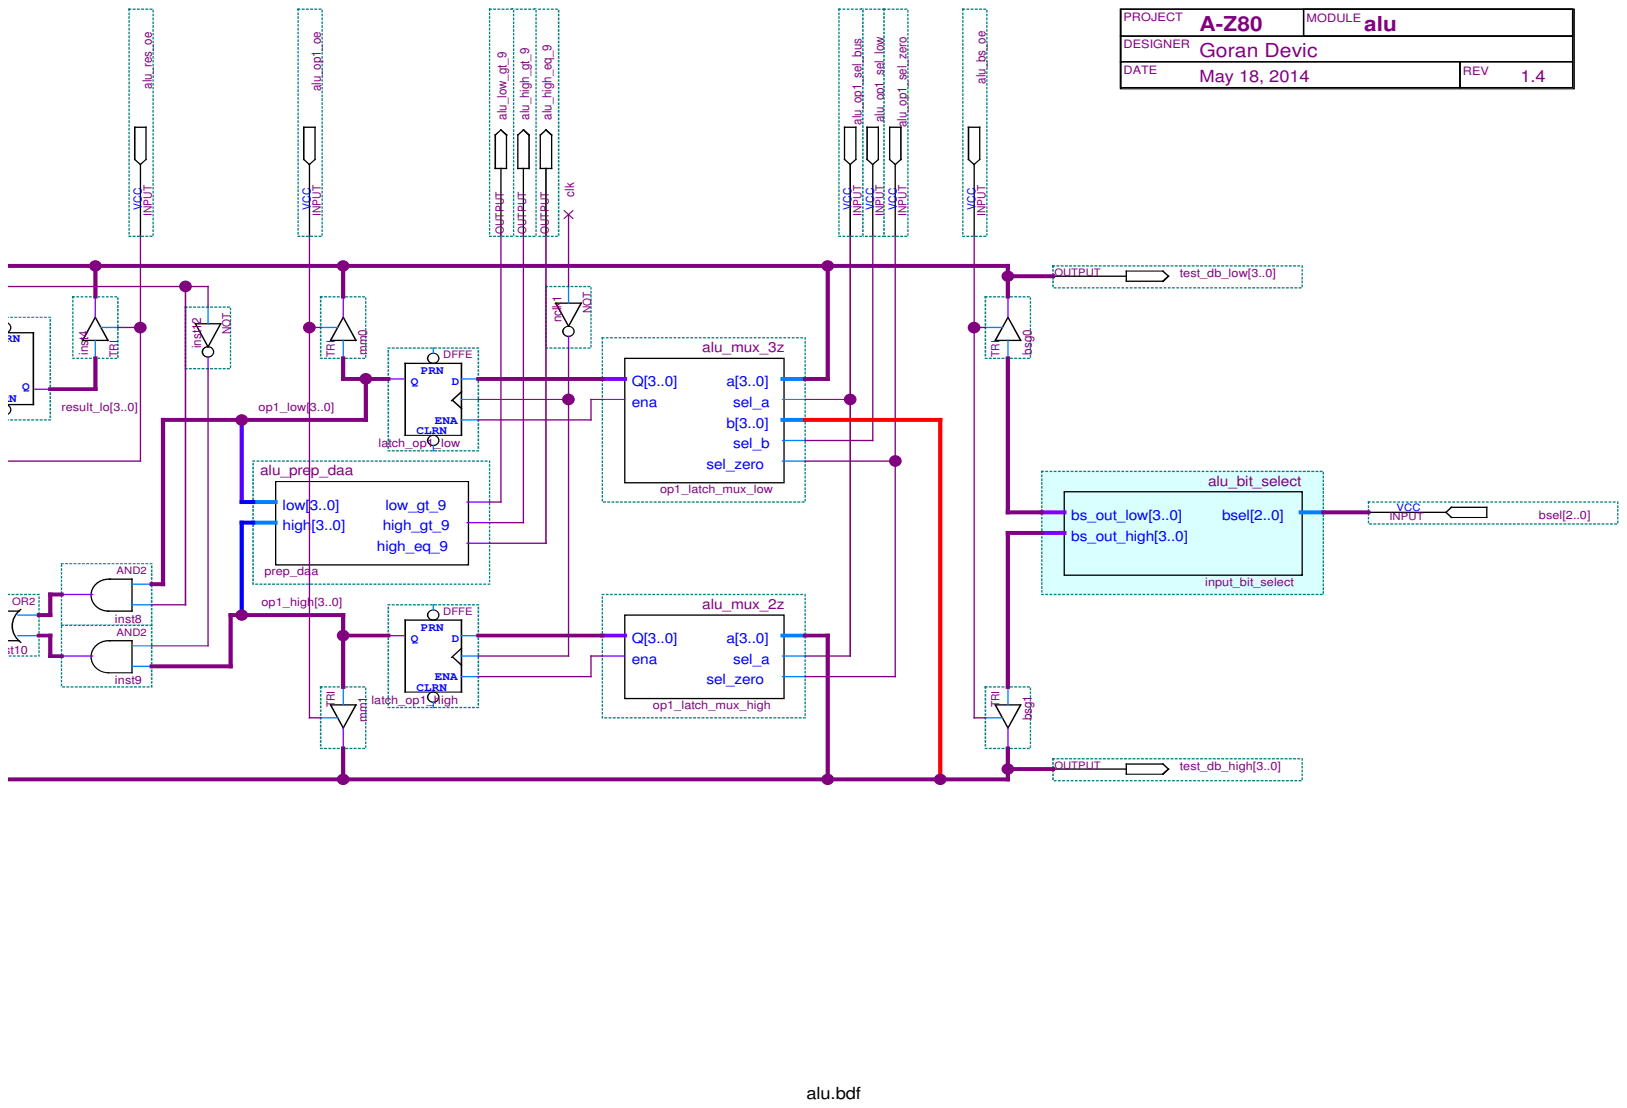
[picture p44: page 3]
clk; op1_low[3..0]; op1_high[3..0]; result_lo[3..0]; VCC; INPUT; bsel[2..0]; alu_bs_oe INPUT; alu_op1_oe INPUT; alu_res_oe INPUT; alu_op1_sel_low INPUT; alu_op1_sel_zero INPUT; alu_op1_sel_bus INPUT; alu_high_eq_9 OUTPUT; alu_high_gt_9 OUTPUT; alu_low_gt_9 OUTPUT; OUTPUT; test_db_low[3..0]; test_db_high[3..0]; AND2; inst8 AND2; inst9; NOT; inst12; TRI; bsg0; bsg1; low[3..0]; high[3..0]; low_gt_9; high_gt_9; high_eq_9; alu_prep_daa; prep_daa; inst4; bs_out_low[3..0]; bs_out_high[3..0]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

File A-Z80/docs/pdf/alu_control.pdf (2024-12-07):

### Bit that is shifted in depends on the opcode: 000 RLC -> old D[7]

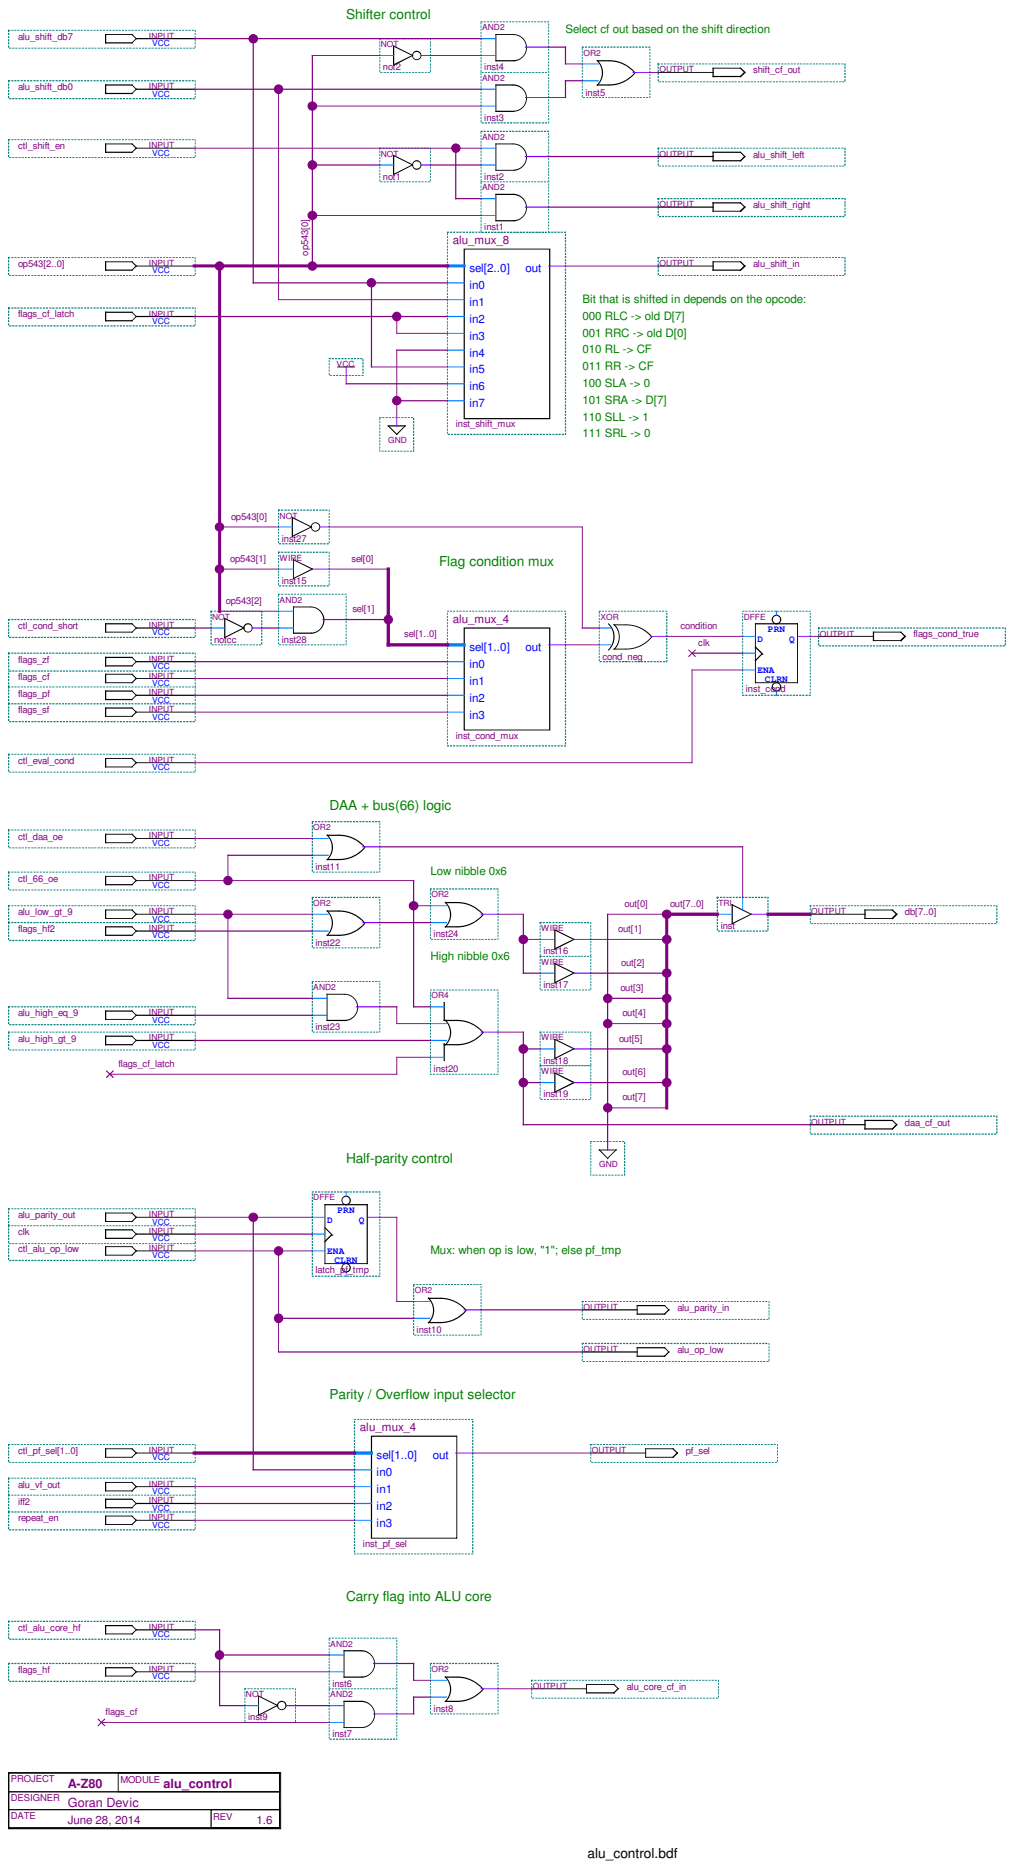
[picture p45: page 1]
alu_control.bdf; out[3]; out[7]; out[0]; out[7..0]; out[4]; out[1]; out[2]; out[5]; out[6]; flags_cf; flags_cf_latch; sel[0]; sel[1]; sel[1..0]; condition; clk; 001 RRC -> old D[0] 010 RL -> CF 011 RR -> CF 100 SLA -> 0 101 SRA -> D[7] 110 SLL -> 1 111 SRL -> 0; Low nibble 0x6; High nibble 0x6; Shifter control; VCC; INPUT; alu_shift_db0; alu_shift_db7; ctl_shift_en; alu_low_gt_9; VCC alu_high_gt_9; alu_high_eq_9; ctl_daa_oe; ctl_alu_op_low; alu_parity_out; flags_zf; VCC flags_pf; flags_sf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

Select cf out based on the shift direction

Flag condition mux

DAA + bus(66) logic

Half-parity control

Mux: when op is low, "1"; else pf_tmp

Parity / Overflow input selector

Carry flag into ALU core

DESIGNER Goran Devic

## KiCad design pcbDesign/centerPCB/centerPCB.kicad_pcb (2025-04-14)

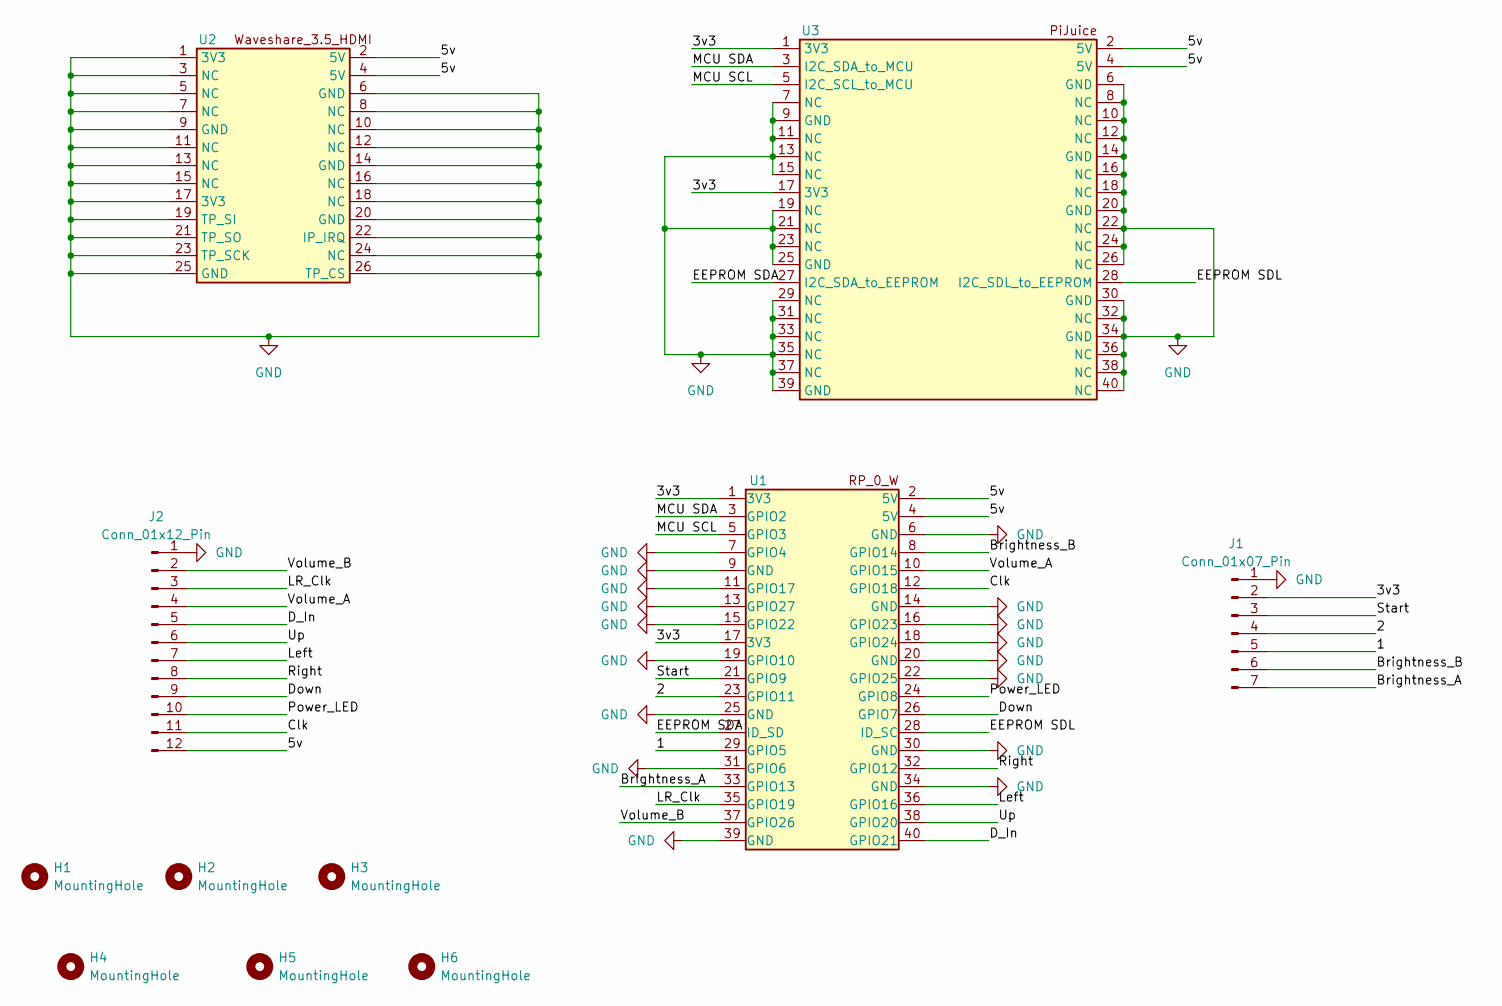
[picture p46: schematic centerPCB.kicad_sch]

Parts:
H1, H2, H3: MountingHole; MountingHole_2.1mm
H4, H5, H6: MountingHole; MountingHole_2.5mm
J1: Conn_01x07_Pin; PinHeader_1x07_P2.54mm_Vertical
J2: Conn_01x12_Pin; PinHeader_1x12_P2.54mm_Vertical
U1, U3: PinHeader_2x20_P2.54mm_Vertical
U2: PinHeader_2x13_P2.54mm_Vertical

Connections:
/1: J1.5, U1.29 (GPIO5)
/2: J1.4, U1.23 (GPIO11)
/3v3: J1.2, U1.1 (3V3), U1.17 (3V3), U3.1 (3V3), U3.17 (3V3)
/5v: J2.12, U1.2 (5V), U1.4 (5V), U2.2 (5V), U2.4 (5V), U3.2 (5V), U3.4 (5V)
/Brightness_A: J1.7, U1.33 (GPIO13)
/Brightness_B: J1.6, U1.8 (GPIO14)
/Clk: J2.11, U1.12 (GPIO18)
/D_In: J2.5, U1.40 (GPIO21)
/Down: J2.9, U1.26 (GPIO7)
/EEPROM SDA: U1.27 (ID_SD), U3.27 (I2C_SDA_to_EEPROM)
/EEPROM SDL: U1.28 (ID_SC), U3.28 (I2C_SDL_to_EEPROM)
/LR_Clk: J2.3, U1.35 (GPIO19)
/Left: J2.7, U1.36 (GPIO16)
/MCU SCL: U1.5 (GPIO3), U3.5 (I2C_SCL_to_MCU)
/MCU SDA: U1.3 (GPIO2), U3.3 (I2C_SDA_to_MCU)
/Power_LED: J2.10, U1.24 (GPIO8)
/Right: J2.8, U1.32 (GPIO12)
/Start: J1.3, U1.21 (GPIO9)
/Up: J2.6, U1.38 (GPIO20)
/Volume_A: J2.4, U1.10 (GPIO15)
/Volume_B: J2.2, U1.37 (GPIO26)
GND: J1.1, J2.1, U1.6 (GND), U1.7 (GPIO4), U1.9 (GND), U1.11 (GPIO17), U1.13 (GPIO27), U1.14 (GND), U1.15 (GPIO22), U1.16 (GPIO23), U1.18 (GPIO24), U1.19 (GPIO10), U1.20 (GND), U1.22 (GPIO25), U1.25 (GND), U1.30 (GND), U1.31 (GPIO6), U1.34 (GND), U1.39 (GND), U2.1 (3V3), U2.3 (NC), U2.5 (NC), U2.6 (GND), U2.7 (NC), U2.8 (NC), U2.9 (GND), U2.10 (NC), U2.11 (NC), U2.12 (NC), U2.13 (NC), U2.14 (GND), U2.15 (NC), U2.16 (NC), U2.17 (3V3), U2.18 (NC), U2.19 (TP_SI), U2.20 (GND), U2.21 (TP_SO), U2.22 (IP_IRQ), U2.23 (TP_SCK), U2.24 (NC), U2.25 (GND), U2.26 (TP_CS), U3.6 (GND), U3.7 (NC), U3.8 (NC), U3.9 (GND), U3.10 (NC), U3.11 (NC), U3.12 (NC), U3.13 (NC), U3.14 (GND), U3.15 (NC), U3.16 (NC), U3.18 (NC), U3.19 (NC), U3.20 (GND), U3.21 (NC), U3.22 (NC), U3.23 (NC), U3.24 (NC), U3.25 (GND), U3.26 (NC), U3.29 (NC), U3.30 (GND), U3.31 (NC), U3.32 (NC), U3.33 (NC), U3.34 (GND), U3.35 (NC), U3.36 (NC), U3.37 (NC), U3.38 (NC), U3.39 (GND), U3.40 (NC)

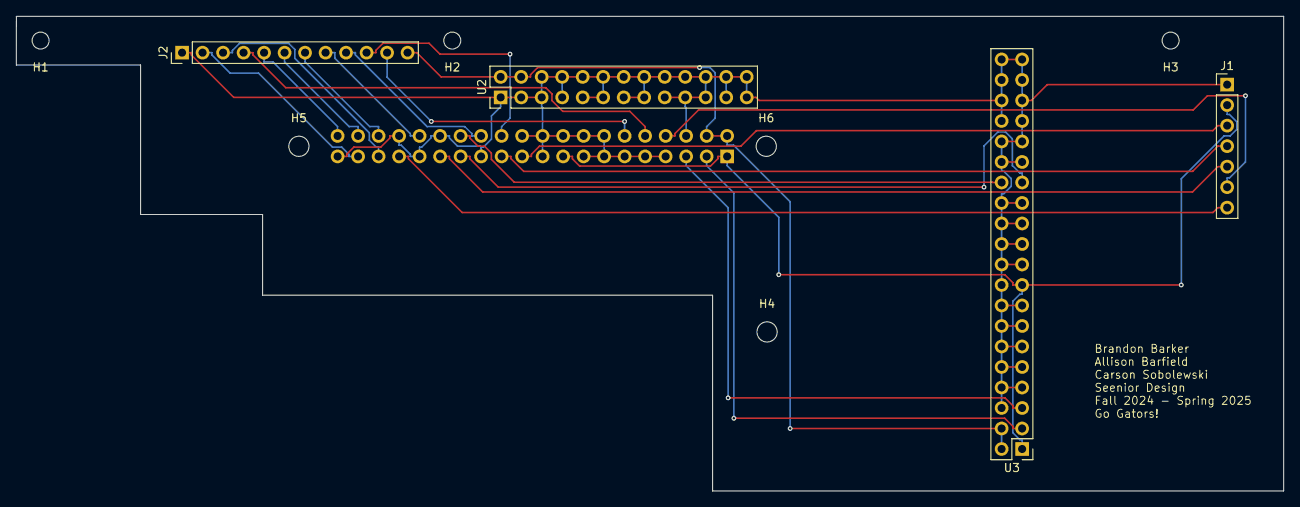
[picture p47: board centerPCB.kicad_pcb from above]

Board: 2 copper layers, 157.0 x 58.8 mm, 11 parts (1 on the bottom side), 22 nets.

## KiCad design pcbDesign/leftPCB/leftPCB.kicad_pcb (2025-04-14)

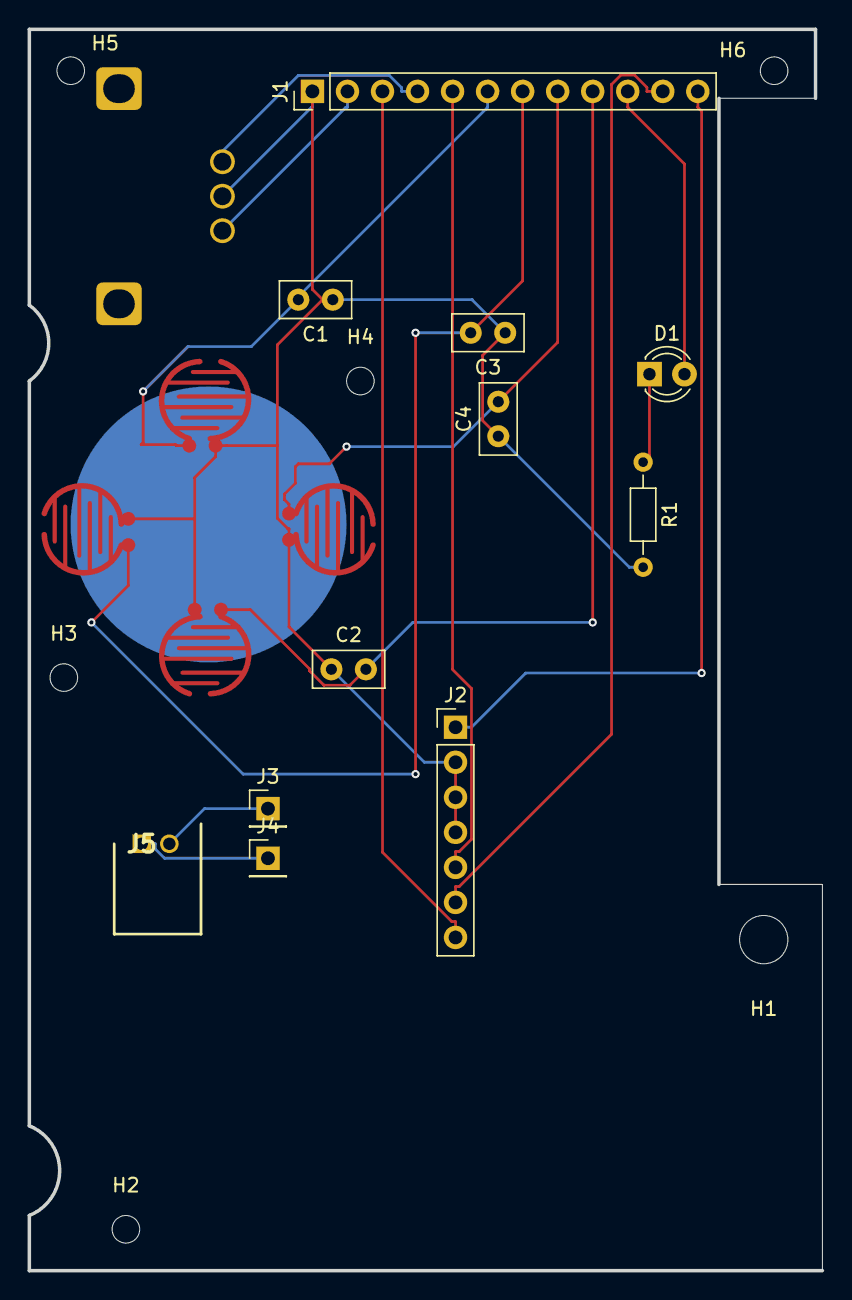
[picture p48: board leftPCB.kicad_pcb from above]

Board: 2 copper layers, 57.5 x 90.0 mm, 22 parts (1 on the bottom side), 15 nets.

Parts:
C1, C2, C3, C4: 1u; C_Disc_D5.0mm_W2.5mm_P2.50mm
D1: LED; LED_D3.0mm
H1: MountingHole; MountingHole_3.5mm
H2, H3, H4, H5, H6: MountingHole; MountingHole_2mm
J1: Conn_01x12_Pin; PinHeader_1x12_P2.54mm_Vertical
J2: Conn_01x07_Pin; PinHeader_1x07_P2.54mm_Vertical
J3, J4: Conn_01x01_Pin; PinHeader_1x01_P2.54mm_Vertical
J5: 440055-2; SHDRRA2W50P0X200_1X2_600X770X525P
R1: R; R_Axial_DIN0204_L3.6mm_D1.6mm_P7.62mm_Horizontal
SW1: UP; BUTTON
SW2: DOWN; BUTTON
SW3: LEFT; BUTTON
SW4: RIGHT; BUTTON
SW5: RotaryEncoder; PES12

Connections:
/5v: J1.12, J2.1
/Clk: J1.11, J2.6
/D_In: J1.5, J2.5
/Down: C2.2, J1.9, SW2.2
/LR_Clk: J1.3, J2.7
/Left: C3.2, J1.7, SW3.2
/Power_LED: D1.2 (A), J1.10
/Right: C4.2, J1.8, SW4.2
/Speaker_Neg: J4.1, J5.1
/Speaker_Pos: J3.1, J5.2
/Up: C1.2, J1.6, SW1.2
/Volume_A: J1.4, SW5.A
/Volume_B: J1.2, SW5.B
GND: C1.1, C2.1, C3.1, C4.1, J1.1, J2.2, J2.3, J2.4, R1.2, SW1.1, SW2.1, SW3.1, SW4.1, SW5.C
unnamed: D1.1 (K), R1.1

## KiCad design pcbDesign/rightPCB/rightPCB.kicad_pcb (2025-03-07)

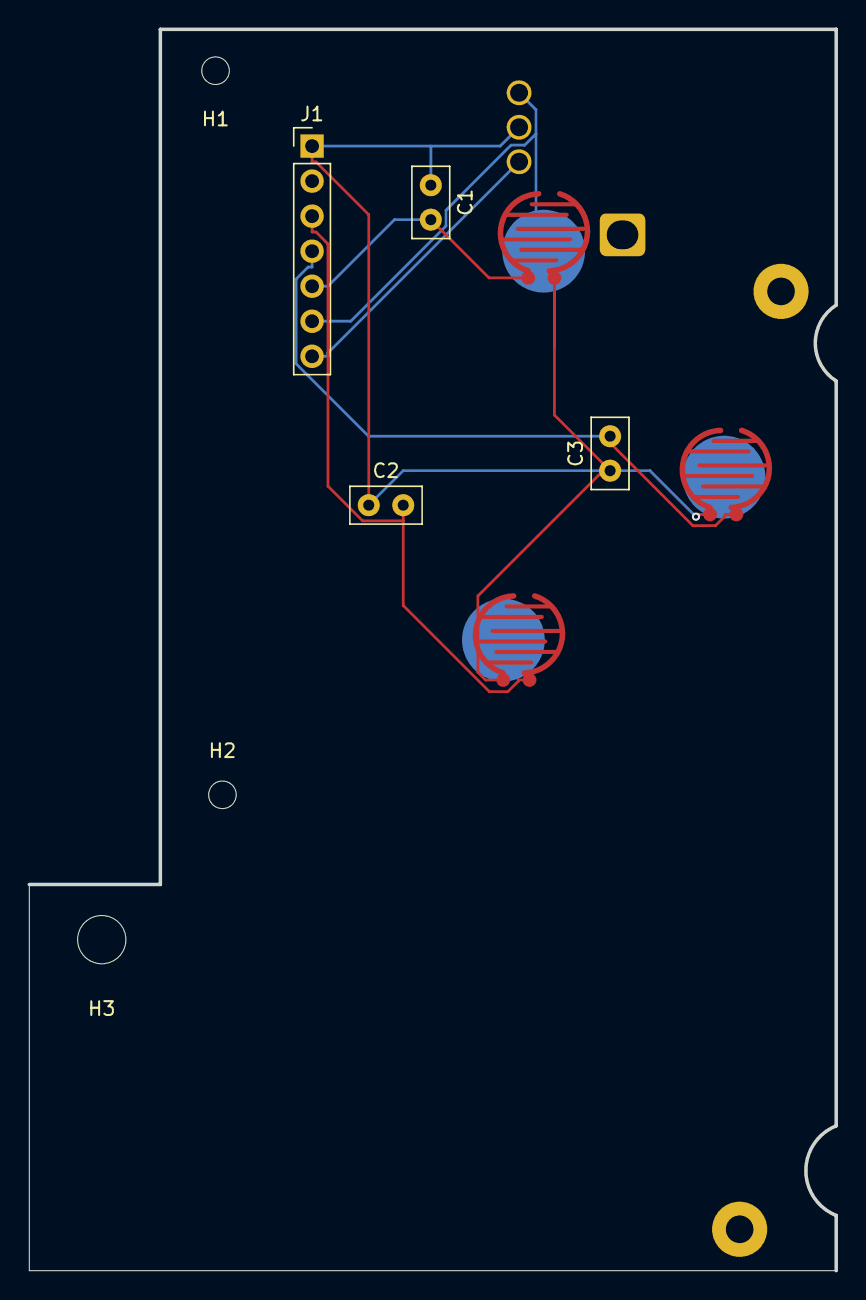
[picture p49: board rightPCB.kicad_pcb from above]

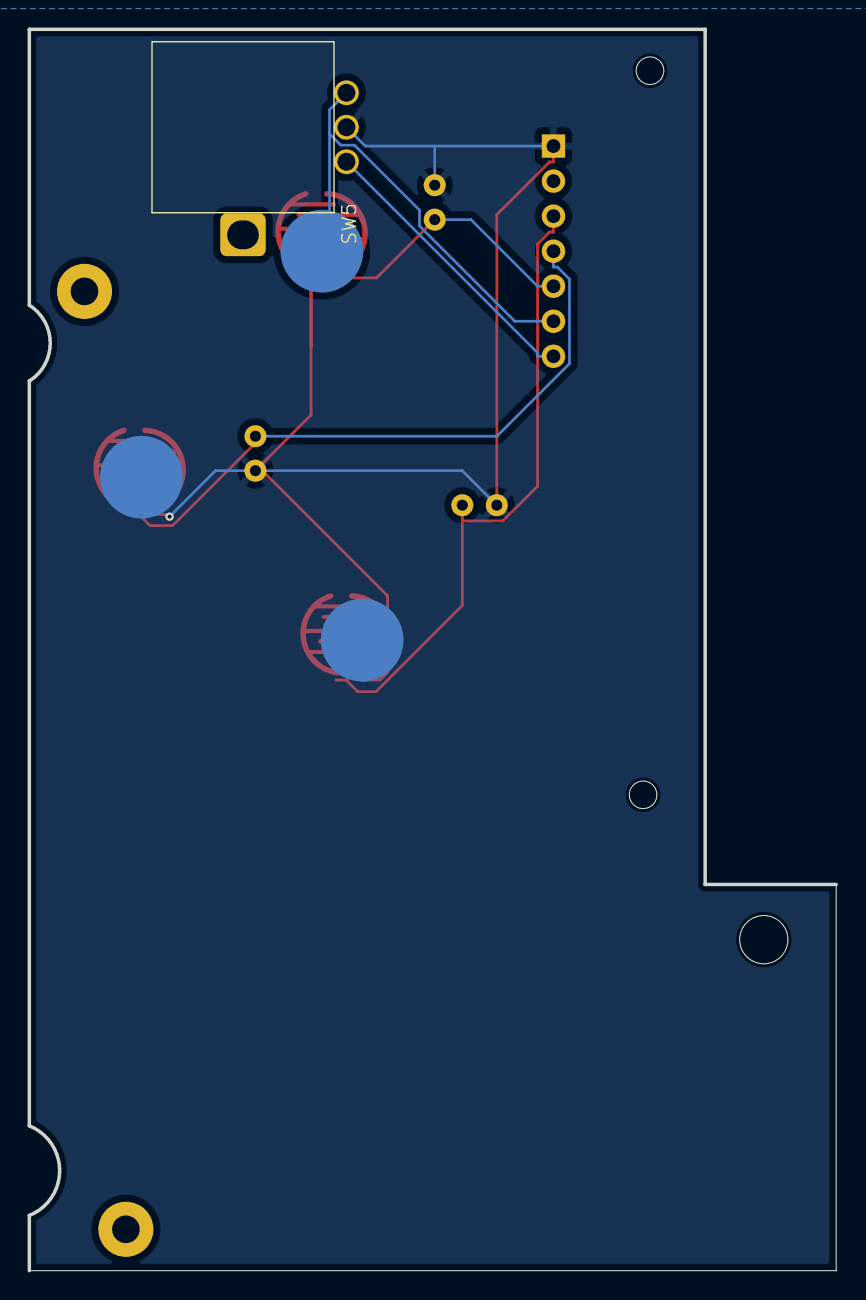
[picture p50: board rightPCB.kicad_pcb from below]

Board: 2 copper layers, 58.5 x 90.0 mm, 13 parts (3 on the bottom side), 6 nets.

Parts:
C1, C2, C3: 1u; C_Disc_D5.0mm_W2.5mm_P2.50mm
H1, H2: MountingHole; MountingHole_2mm
H3: MountingHole; MountingHole_3.5mm
J1: Conn_01x07_Pin; PinHeader_1x07_P2.54mm_Vertical
Pad_gge24769: Pad_gge24769
Pad_gge24780: Pad_gge24780
SW5: RotaryEncoder; PES12
SW6: TL; BUTTON
SW7: TR; BUTTON
SW8: PS; BUTTON

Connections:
/1: C2.2, J1.3, SW6.1
/2: C3.2, J1.4, SW7.1
/Brightness_A: J1.7, SW5.A
/Brightness_B: J1.6, SW5.B
/Start: C1.2, J1.5, SW8.2
GND: C1.1, C2.1, C3.1, J1.1, SW5.C, SW6.2, SW7.2, SW8.1

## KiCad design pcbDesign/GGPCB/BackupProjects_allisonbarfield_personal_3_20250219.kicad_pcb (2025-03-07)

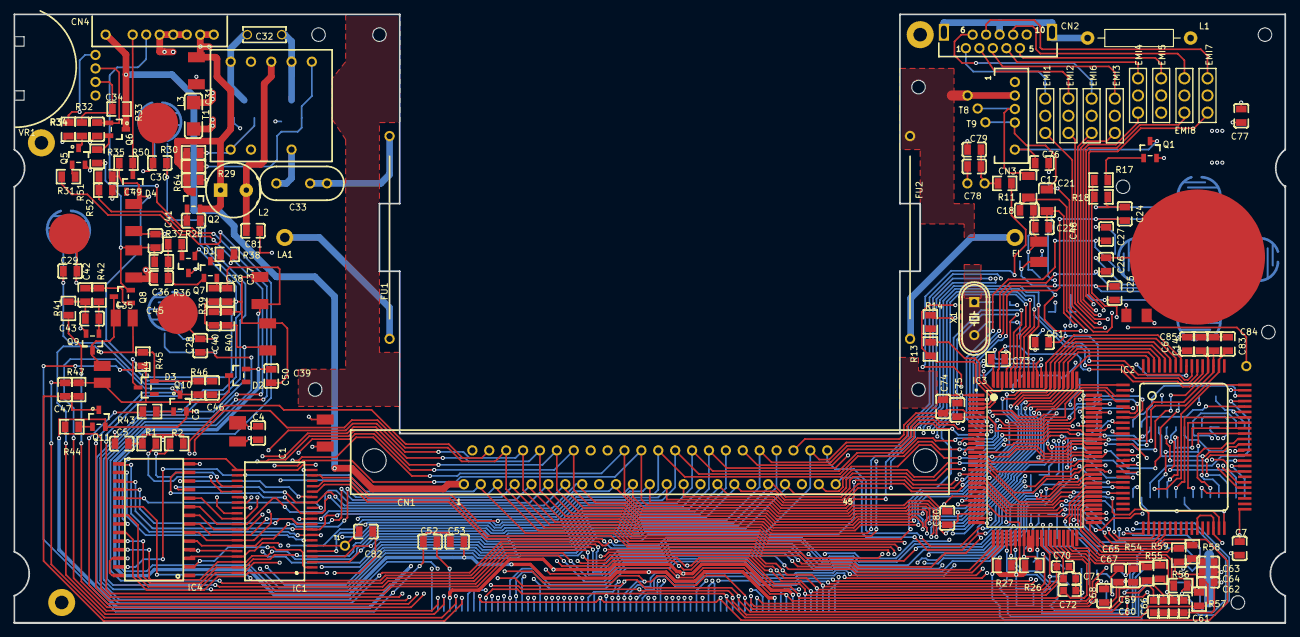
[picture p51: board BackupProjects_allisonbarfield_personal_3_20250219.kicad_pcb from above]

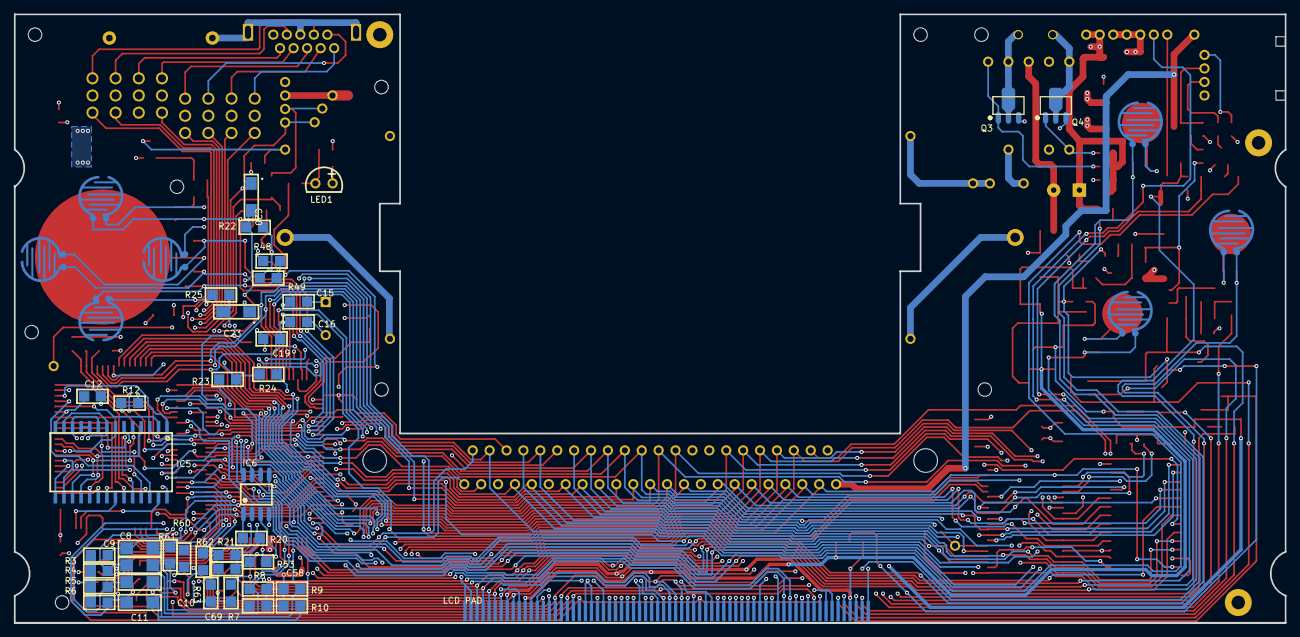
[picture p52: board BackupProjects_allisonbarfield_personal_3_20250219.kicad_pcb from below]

Board: 4 copper layers, 188.0 x 90.0 mm, 208 parts (47 on the bottom side), 196 nets.

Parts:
C1, C3, C6, C31, C35, C37, C39, C44, C45, C48, C49: 1u; CAPASITOR TEST
C4, C5, C7, C14, C18, C22, C24, C25, C26, C27, C28, C29, C30, C34, C36, C38, C40, C41, C42, C43, C46, C47, C50, C51, C52, C53, C65, C67, C68, C73, C74, C75, C76, C77, C78, C79, C80, C81, C82, C83, C84, C85: 1u; C0805
C8, C9, C10, C11: 1u; 1806
C12, C15, C16, C19, C58, C69: 1u; C1205
C17, C21: 1u; C1206
C20, C23: 1u; C20,23
C32: 1u; CERAMIC-5.08
C33: 1u; CAP33
C59, C60, C61, C62, C63, C64, C66, C70, C71, C72: 1u; C0603
CN1: CONN 45P FOR GG 01; CN1
CN2: CONN 10P FOR GG; CN2
CN3: WIRE HARN SP FOR GG; CONNECTOR3
CN4: CN4
D1, D2, D4: 1SS184; SOT-23-3_L2.9-W1.3-P1.90-LS2.4-TR
D3: 1SS184; TO-236MOD_L2.9-W1.5-P0.95-LS2.5-BR
EMI1, EMI2, EMI3, EMI4, EMI5, EMI6, EMI7, EMI8: EMI; FILTER-TH_3P-L8.0-W2.5-P2.54-R
FU1, FU2: Glass tube fuse2A 3F 250VAC; FUSE
Hole_gge24781: Hole_gge24781
Hole_gge24790: Hole_gge24790
Hole_gge24795: Hole_gge24795
Hole_gge24800: Hole_gge24800
Hole_gge24805: Hole_gge24805
Hole_gge24816: Hole_gge24816
Hole_gge24821: Hole_gge24821
Hole_gge24826: Hole_gge24826
Hole_gge24831: Hole_gge24831
IC1: TMPZ84C00AM-6; SSOP-40
IC2: 315-5377; 80-QFP
IC3: 315-5378B; 100QFP
IC4: MB8464A-10LL; FP-28DA
IC5: HM65256BLFP-10T; FP-28DA
IC6: IC6; KM 8SOP 5X6
L1: 1m; CHOKE_HORIZONTAL_RM15MM
L2: 1m; 100UH-3A
L3: 1m; L1806
LA1: Lamp; LAMP
LED1: LED; LED-TH_2P-L4.80-W3.80-P2.54-L
Pad_gge24769: Pad_gge24769
Pad_gge24780: Pad_gge24780
Pad_gge24811: Pad_gge24811
Pad_gge85411: Pad_gge85411
Pad_gge90736: Pad_gge90736
Pad_gge109066: Pad_gge109066
Pad_gge109074: Pad_gge109074
Pad_gge109081: Pad_gge109081
Q1, Q7: 2SC1623; SOT-23-3_L2.9-W1.3-P1.90-LS2.4-TR
Q2: 2SC1623???; SOT-23-3_L2.9-W1.3-P1.90-LS2.4-TR
Q3, Q4: 2sd1614; SOT89-3L
Q5, Q6, Q9, Q11: 2SC1623; SOT-23-3_L2.9-W1.3-P1.90-LS2.4-L
Q8: 2SA812; SOT-23-3_L2.9-W1.3-P1.90-LS2.4-TR
Q10: 2SA812; SOT-23-3_L2.9-W1.3-P1.90-LS2.4-L
R1, R2, R11, R13, R14, R17, R18, R26, R27, R30, R31, R32, R33, R34, R35, R36, R37, R38, R39, R40, R41, R42, R43, R44, R45, R46, R47, R50, R51, R52, R54, R55, R56, R57, R58, R59, R64: 0; R0805
R3, R4, R5, R6, R7, R8, R9, R10, R12, R20, R21, R22, R23, R24, R25, R48, R49, R53, R60, R61, R62, R63: 0; R1205
R28, R29: 0; C0805
SW1: UP; BUTTON
SW2: DOWN; BUTTON
SW3: LEFT; BUTTON
SW4: RIGHT; BUTTON
SW5: TL; BUTTON
SW6: TR; BUTTON
SW7: PS; BUTTON
T1: Transformer T1; TR1
U1: LCD PAD; LCD
VR1: 20K; VR1
X1: 32.2159MHz; HC-49US_L11.5-W4.5-P4.88

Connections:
+2.5V: C48.1, R7.1, R8.1, R9.1, R10.1, R26.1, R27.2, R48.2, R49.1
+5V: C1.1, C3.1, C4.1, C5.1, C6.1, C7.1, C12.1, C14.1, C31.1, C51.1, C77.2, C78.2, C80.1, CN1.2, CN1.35, CN4.1, CN4.2, EMI5.1, IC1.11, IC2.2, IC2.12, IC2.41, IC3.2, IC3.24, IC3.29, IC3.52, IC3.79, IC4.26, IC4.28, IC5.28, L2.1, L3.1, LED1.1, Q2.1, Q2.3, R1.1, R2.1, R12.2, R29.1, R30.1, R38.2, R64.2, U1.10, U1.30, U1.50
+34V: CN1.1, CN4.9, Q6.1, R33.2
A0: CN1.12, IC1.30, IC2.69, IC3.99, IC4.10
A1: CN1.11, IC1.31, IC3.98, IC4.9
A2: CN1.10, IC1.32, IC3.97, IC4.8
A3: CN1.9, IC1.33, IC3.96, IC4.7
A4: CN1.8, IC1.34, IC3.95, IC4.6
A5: CN1.7, IC1.35, IC3.94, IC4.5
A6: CN1.6, IC1.36, IC2.70, IC3.93, IC4.4
A7: CN1.5, IC1.37, IC2.71, IC3.92, IC4.3
A8: CN1.31, IC1.38, IC3.91, IC4.25
A9: CN1.30, IC1.39, IC3.90, IC4.24
A10: CN1.25, IC1.40, IC3.89, IC4.21
A11: CN1.29, IC1.1, IC4.23
A12: CN1.4, IC1.2, IC4.2
A13: CN1.32, IC1.3
A14: CN1.33, IC1.4, IC2.3
A15: CN1.28, IC1.5, IC2.4
AD0: IC2.45, IC5.10, IC5.11
AD1: IC2.46, IC5.9, IC5.12
AD2: IC2.48, IC5.8, IC5.13
AD3: IC2.49, IC5.7, IC5.15
AD4: IC2.50, IC5.6, IC5.16
AD5: IC2.51, IC5.5, IC5.17
AD6: IC2.53, IC5.4, IC5.18
AD7: IC2.54, IC5.19
ANALOG+5V: C19.1, CN3.1, IC6.8, L3.2, R3.2, R4.2, R5.2, R6.2, R48.1
C8_1: C8.1, IC3.36, R7.2
C9_2: C9.2, IC2.14, R4.1
C10_2: C10.2, IC2.15, R5.1
C11_2: C11.2, IC2.16, R6.1
C17_1: C17.1, C18.1, R20.2, R21.2
C21_1: C21.1, C22.2, R23.2, R24.2
C23_2: C23.2, CN1.45, R25.2
C32_1: C32.1, Q4.2, T1.1
C32_2: C32.2, Q3.2, T1.4
C33_1: C33.1, T1.8
C42_2: C42.2, C43.2, R41.1
C44_1: C44.1, C47.2, D2.3, R45.2, R47.2, U1.64
C45_2: C45.2, C46.2, D3.2, R45.1, R46.2, U1.66
C46_1: C46.1, Q10.1, R46.1, U1.67
C73_1: C73.1, IC3.100
CCLK: C74.2, CN1.40, IC3.5
CL2: IC3.46, U1.9, U1.29, U1.49
CLA1: C64.2, R59.2, U1.15
CLA2: C66.2, R61.2, U1.35
CLA3: C68.2, R63.2, U1.55
CLB1: C63.2, R58.2, U1.14
CLB2: C65.2, R60.2, U1.34
CLB3: C67.2, R62.2, U1.54
CLK: C82.2, IC1.6, Pad_gge85411.3
CN3_3: C17.2, CN3.3, Pad_gge109074.6
CN3_4: C21.2, CN3.4, Pad_gge109081.7
CN3_5: C76.1, CN3.5, IC3.25, Q1.3
CN4_6: CN4.6, IC3.30
CN4_7: CN4.7, D4.3, R50.1
D0: CN1.13, IC1.14, IC2.73, IC3.88, IC4.11
D1: CN1.14, IC1.15, IC2.74, IC3.87, IC4.12
D01: C61.2, R56.2, U1.18, U1.38, U1.58
D2: CN1.15, IC1.12, IC2.75, IC3.86, IC4.13
D02: C59.2, R54.2, U1.16, U1.36, U1.56
D3: CN1.19, IC1.8, IC2.76, IC3.85, IC4.15
D03: C62.2, R57.2, U1.19, U1.39, U1.59
D4: CN1.20, IC1.7, IC2.77, IC3.84, IC4.16
D04: C60.2, R55.2, U1.17, U1.37, U1.57
D5: CN1.21, IC1.9, IC2.78, IC3.83, IC4.17
D6: CN1.22, IC1.10, IC2.79, IC3.82, IC4.18
D7: CN1.23, IC1.13, IC2.1, IC3.81, IC4.19
DB: C58.2, R53.2, U1.3, U1.23, U1.43
DOWN: C25.2, IC3.8, SW2.1
DW: IC3.51, U1.20, U1.40, U1.60
EMI1_1: EMI1.1, IC3.72
EMI1_3: CN2.1, EMI1.3
EMI2_1: EMI2.1, IC3.73
EMI2_3: CN2.2, EMI2.3
EMI3_1: EMI3.1, IC3.74
EMI3_3: CN2.3, EMI3.3
EMI4_1: EMI4.1, IC3.75
EMI4_3: CN2.4, EMI4.3
EMI5_3: CN2.5, EMI5.3
EMI6_1: EMI6.1, IC3.76
EMI6_3: CN2.6, EMI6.3
EMI7_1: EMI7.1, IC3.78
EMI7_3: CN2.7, EMI7.3
EMI8_1: EMI8.1, IC3.77
EMI8_3: CN2.9, EMI8.3
EXM1: CN1.34, IC2.6
EXM2: CN1.27, IC2.7
FU1_1: C33.2, FU1.1
FU1_2: FU1.2, LA1.2
GG: CN1.42, IC3.66, R12.1, R31.1
GND: C1.2, C3.2, C4.2, C5.2, C6.2, C7.2, C12.2, C14.2, C15.2, C16.2, C18.2, C19.2, C22.1, C24.1, C25.1, C26.1, C27.1, C28.1, C29.1, C30.1, C31.2, C34.1, C35.2, C36.1, C41.1, C48.2, C49.2, C51.2, C58.1, C59.1, C60.1, C61.1, C62.1, C63.1, C64.1, C65.1, C66.1, C67.1, C68.1, C69.1, C70.1, C71.1, C72.1, C73.2, C74.1, C75.1, C76.2, C77.1, C79.1, C80.2, C81.1, C82.1, C83.2, C84.2, C85.2, CN1.16, CN1.17, CN1.18, CN1.41, CN3.2, CN4.3, CN4.4, CN4.5, D1.3, EMI1.2, EMI2.2, EMI3.2, EMI4.2, EMI5.2, EMI6.2, EMI7.2, EMI8.2, FU2.1, IC1.29, IC2.11, IC2.25, IC2.35, IC2.38, IC2.52, IC2.59, IC2.63, IC3.1, IC3.19, IC3.28, IC3.39, IC3.40, IC3.53, IC3.80, IC4.14, IC5.3, IC5.14, IC6.4, L1.1, Pad_gge109066.5, Q1.1, Q3.3, Q4.3, Q5.2, Q9.2, R18.1, R22.1, R25.1, R34.1, R49.2, R52.2, R64.1, SW1.1, SW2.2, SW3.1, SW4.1, SW5.2, SW6.2, SW7.1, T1.2, U1.1, U1.2, U1.13, U1.21, U1.22, U1.33, U1.41, U1.42, U1.53, U1.61, U1.62, U1.68
IC1_24: IC1.24, R2.2
IC1_25: IC1.25, R1.2
IC1_26: CN1.39, IC1.26, IC2.64, IC3.26
IC2_17: IC2.17, IC3.14
IC2_18: IC2.18, IC3.15
IC2_19: IC2.19, IC3.16
IC2_20: IC2.20, IC3.17
IC2_21: IC2.21, IC3.18
IC2_26: IC2.26, IC3.20
IC2_27: IC2.27, IC3.21
IC2_28: IC2.28, IC3.22
IC2_29: IC2.29, IC3.23
IC4_20: IC2.8, IC4.20
IC5_1: IC2.62, IC5.1
IC5_2: IC2.60, IC5.2
IC5_20: IC2.44, IC5.20
IC5_21: IC2.57, IC5.21
IC5_22: IC2.40, IC5.22
IC5_23: IC2.58, IC5.23
IC5_24: IC2.56, IC5.24
IC5_25: IC2.55, IC5.25
IC5_26: IC2.61, IC5.26
IC5_27: IC2.39, IC5.27
IC6_3: IC3.38, IC6.3, R26.2
IC6_5: IC3.37, IC6.5, R27.1
INT: IC1.16, IC2.72
IORQ: C85.1, CN1.37, IC1.20, IC2.68, IC3.69
L1_2: CN2.8, L1.2
L2_2: C81.2, L2.2, T1.3
LA1_1: FU2.2, LA1.1
LCD: IC3.64, R17.1, R18.2, R28.1
LE: C26.2, IC3.9, SW3.2
LED1_2: C78.1, C79.2, LED1.2, R11.1
M1: CN1.36, IC1.27, IC3.68
MREQ: CN1.24, IC1.19, IC2.5
NMI: IC1.17, IC3.67
P1: C72.2, IC3.45, U1.7, U1.27, U1.47
P2: C70.2, IC3.43, U1.5, U1.25, U1.45
P3: C69.2, IC3.42, U1.4, U1.24, U1.44
P4: C71.2, IC3.44, U1.6, U1.26, U1.46
PS: C30.2, IC3.13, SW7.2
Q1_2: Q1.2, R17.2
Q2_2: Q2.2, R28.2
Q3_1: Q3.1, R29.2, T1.5
Q4_1: Q4.1, R30.2, T1.6
Q5_1: Q5.1, R32.1
Q6_2: Q6.2, R35.1
Q8_2: C42.1, Q8.2, R42.2
Q8_3: C44.2, C45.1, Q8.3, Q9.1
Q9_3: C43.1, Q9.3, R42.1
Q10_3: Q10.3, R43.1
Q11_3: Q11.3, R44.1
R3_1: C8.2, IC2.13, R3.1
R8_2: C9.1, IC3.35, R8.2
R9_2: C10.1, IC3.34, R9.2
R10_2: C11.1, IC3.33, R10.2
R11_2: IC3.27, R11.2
R13_2: IC3.4, R13.2, R14.2
R20_1: IC6.1, IC6.2, R20.1
R21_1: C20.1, R21.1
R22_2: C20.2, CN1.44, R22.2
R23_1: IC6.6, IC6.7, R23.1
R24_1: C23.1, R24.1
R31_2: Q5.3, R31.2
R35_2: C35.1, C41.2, Q8.1, R35.2, R36.2
R36_1: C36.2, Q7.2, R36.1, R37.2
R37_1: D1.1, R37.1
R38_1: Q7.3, R38.1
R39_2: C37.1, C38.2, C50.2, C53.2, D2.1, Q7.1, R39.2, U1.11, U1.31, U1.51
R40_1: C37.2, C38.1, C39.2, C40.1, C50.1, C52.1, C53.1, D1.2, D3.3, R40.1, U1.12, U1.32, U1.52
R40_2: C39.1, C40.2, C52.2, Q10.2, Q11.2, R39.1, R40.2, U1.8, U1.28, U1.48, U1.65
R41_2: IC3.62, R41.2
R43_2: IC3.61, R43.2
R44_2: IC3.60, R44.2
R47_1: C47.1, Q11.1, R47.1, U1.63
R51_1: C49.1, D4.1, IC3.32, R50.2, R51.1
R52_1: IC3.31, R51.2, R52.1
R53_1: IC3.41, R53.1
R58_1: IC3.54, R58.1
R59_1: IC3.55, R59.1
R60_1: IC3.56, R60.1
R61_1: IC3.57, R61.1
R62_1: IC3.58, R62.1
R63_1: IC3.59, R63.1
RD: C83.1, CN1.26, IC1.21, IC2.66, IC3.71, IC4.22
RFSH: CN1.38, IC1.28
RI: C27.2, IC3.10, SW4.2
SAMP: IC3.63, Pad_gge90736.4
T3: IC3.49, R56.1
T4: IC3.47, R54.1
T5: IC3.50, R57.1
T6: IC3.48, R55.1
TL: C28.2, IC3.11, SW5.1
TR: C29.2, IC3.12, SW6.1
TV: CN1.43, IC3.65
UP: C24.2, IC3.7, SW1.2
VCLK: C75.2, IC2.10, IC3.6
VR1_1: R34.2, VR1.1
VR1_2: C34.2, Q6.3, VR1.2
VR1_3: R32.2, R33.1, VR1.3
WR: C84.1, CN1.3, IC1.22, IC2.67, IC3.70, IC4.27
X1_1: C15.1, IC3.3, R13.1, X1.1
X1_2: C16.1, R14.1, X1.2

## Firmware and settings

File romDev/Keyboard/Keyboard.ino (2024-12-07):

/* Arduino USB HID Keyboard Demo
 * Random Key/Random Delay
 */


#define D2 2
#define D3 3
#define D4 4
#define D5 5
#define D6 6
#define D7 7

bool press;

uint8_t buf[8] = { 
  0 }; 	/* Keyboard report buffer */

void setup() 
{
  pinMode(D2, INPUT);
  pinMode(D3, INPUT);
  pinMode(D4, INPUT);
  pinMode(D5, INPUT);
  pinMode(D6, INPUT);
  pinMode(D7, INPUT);
  Serial.begin(9600);
  randomSeed(analogRead(0));
  delay(200);
}

void loop() 
{
  press = false;
  if (digitalRead(D2) == HIGH) {
    buf[2] = 4; //A
    //Serial.write(buf, 8);
    press = true;
  }
  else {
    buf[2] = 0;
  }
  if (digitalRead(D3) == HIGH) {
    buf[3] = 82; //Up
    //Serial.write(buf, 8);
    press = true;
  }
  else {
    buf[3] = 0;
  }
  if (digitalRead(D4) == HIGH) {
    buf[4] = 80; //Left
    //Serial.write(buf, 8);
    press = true;
  }
  else {
    buf[4] = 0;
  }
  if (digitalRead(D5) == HIGH) {
    buf[5] = 81; //Down
    //Serial.write(buf, 8);
    press = true;
  }
  else {
    buf[5] = 0;
  }
  if (digitalRead(D6) == HIGH) {
    buf[6] = 79; //Right
    //Serial.write(buf, 8);
    press = true;
  }
  else {
    buf[6] = 0;
  }
  if (digitalRead(D7) == HIGH) {
    buf[7] = 22; //S
    //Serial.write(buf, 8);
    press = true;
  }
  else {
    buf[7] = 0;
  }

  Serial.write(buf, 8);
  
}

void releaseKey() 
{
  buf[0] = 0;
  buf[2] = 0;
  Serial.write(buf, 8);	// Release key  
}

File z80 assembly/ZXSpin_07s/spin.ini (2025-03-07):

[ConfigFolder]
ConfigFolder=[SPINDir]\

[MRU List]
File0=
File1=
File2=
File3=
File4=
File5=
File6=
File7=
File8=
File9=

[MRU Tapes]
File0=
File1=
File2=
File3=
File4=
File5=
File6=
File7=
File8=
File9=

[MRU ASM]
File0=C:\Users\barke\Documents\Computer Engineering Design\game-gear\z80 assembly\carGame\carGame.asm
File1=
File2=
File3=
File4=
File5=
File6=
File7=
File8=
File9=

[TZXBrowser]
AdvancedWidth=320
ViewAdvanced=0

[WindowPlacements]
DebuggerSelectionForm=382,76,258,344
FSWindow=0,0,329,243
PaletteEditorForm=64,82,576,338
MicroDrivesForm=216,206,362,214
BreakPointInputForm=244,215,347,205
Form4=364,374,541,306
VideoForm=46,142,546,278
DebuggerInputForm=195,227,333,193
DebuggerFindForm=163,226,408,194
ZipForm=188,94,258,326
TZXBrowserForm=110,79,530,341
TZXPropertiesForm=145,125,302,295
MessageForm=330,324,315,155
DiskBoxForm=255,269,324,151
SticksForm=163,153,360,267
HDFManager=206,89,311,331
BinaryFilesForm=317,313,340,291
AudioForm=245,137,344,283
KeyboardForm=179,158,424,262
OptionsFormNew=52,0,588,462
RZXSnapWindow=214,248,394,172
DebuggerForm=5,27,635,393
DataTypesForm=151,254,454,166
ProfilerForm=88,283,529,173
ZXPrinterForm=256,236,373,184
PrintForm=260,0,309,522
PokesForm=207,39,433,381
GameFinderForm=139,134,449,286
AsmFindForm=195,231,387,189
POKEEditorForm=170,2,279,418
SPINMainWindow=299,191,376,424

[WindowVisible]
DebuggerSelectionForm=0
FSWindow=0
PaletteEditorForm=0
MicroDrivesForm=0
BreakPointInputForm=0
Form4=0
VideoForm=0
DebuggerInputForm=0
DebuggerFindForm=0
ZipForm=0
TZXBrowserForm=0
TZXPropertiesForm=0
MessageForm=0
DiskBoxForm=0
SticksForm=0
HDFManager=0
BinaryFilesForm=0
AudioForm=0
KeyboardForm=0
OptionsFormNew=0
RZXSnapWindow=0
DebuggerForm=0
DataTypesForm=0
ProfilerForm=0
ZXPrinterForm=0
PrintForm=0
PokesForm=0
GameFinderForm=0
AsmFindForm=0
POKEEditorForm=0
SPINMainWindow=1

[WindowNonClient]
DebuggerSelectionForm=6,29
FSWindow=0,0
PaletteEditorForm=6,29
MicroDrivesForm=33,39
BreakPointInputForm=6,29
Form4=6,29
VideoForm=6,29
DebuggerInputForm=6,29
DebuggerFindForm=6,29
ZipForm=16,39
TZXBrowserForm=16,39
TZXPropertiesForm=6,29
MessageForm=6,29
DiskBoxForm=6,29
SticksForm=6,29
HDFManager=6,29
BinaryFilesForm=6,29
AudioForm=6,29
KeyboardForm=6,29
OptionsFormNew=6,29
RZXSnapWindow=33,39
DebuggerForm=16,39
DataTypesForm=6,29
ProfilerForm=16,39
ZXPrinterForm=16,39
PrintForm=6,29
PokesForm=6,29
GameFinderForm=16,39
AsmFindForm=6,29
POKEEditorForm=6,29
SPINMainWindow=16,59

[Hidden]
UseBin=0

[Debugger]
OutAddress=1
OutInstructionBytes=1
OutLowerCase=1
OutSourceFormat=1
OutDEFBs=1
OutTabs=1
AllowRomEdit=0
DisplayHex=0
IgnoreBPPage=0
Reg8Bit=0

[Assembler]
AllowRomAsm=0
GenDebugInfo=0
DefsDefault=255

[Editor]
CreateBackups=0
ConvertTabs=0
TabAsSpace=0

[Visual]
SyntaxHighlighting=1
TextFontName=Courier New
TextFontSize=10
HighlightEdit=1
UseZXChars=1
TextDisplay=0
TabSize=8
SkinWindows=0

[Video]
VideoFCC=none
Width=352
Height=352
FPS=25
KFInterval=300
Quality=750
BPS=1500
Flags=0
Filename=
AudioWFormatTag=0
AudioNChannels=0
AudioNSamplesPerSec=0
AudioNAvgBytesPerSec=0
AudioNBlockAlign=0
AudioWBitsPerSample=0
AudioExtraInfo=

[Palettes]
Palette0=Default Spectrumÿ0000000000CACA0000CA00CA00CA0000CACACACA00C5C7C50000000000FFFF0000FF00FF00FF0000FFFFFFFF00FFFFFF

[Configurations]
LastConfiguration=[SPINDir]\Default.spincfg
1=[SPINDir]\Default.spincfg

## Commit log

2024-12-02 Created a "Hello World" ROM in the .gg file format to be run on any Game Gear emulator
2024-12-06 Updated movement and included code for button implementation on an Arduino
2024-12-06 Z80 Implementation FPGA
    [Spectrum-VGA-timings.xlsx, Timings.csv, Timings.xlsm]
2024-12-07 Created Readme for ROM development and added Arduino files
2025-02-01 Added schematic for custom controller
    [AdafruitFeatherController.kicad_pcb, AdafruitFeatherController.kicad_sch]
2025-02-20 Added schematic and pcb for original game gear main PCB and started designing schematic and pcb for the project's main pcb
    [BackupProjects_allisonbarfield_personal_3_20250219.kicad_pcb, BackupProjects_allisonbarfield_personal_3_20250219.kicad_sch, mainPCB.kicad_pcb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]
2025-02-21 fixed error in pcb border
    [mainPCB.kicad_pcb]
2025-02-24 Finalized pcb outline. There are now 3 pcbs instead of 1 to allow all components to fit. Also added some components.
    [centerPCB.kicad_pcb, centerPCB.kicad_sch, leftPCB.kicad_pcb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]
2025-03-04 Updated pcbs and added footprint for rotary encoder (in progress)
    [centerPCB.kicad_pcb, centerPCB.kicad_sch, leftPCB.kicad_pcb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]
2025-03-04 finalized center pcb component placement
    [centerPCB.kicad_pcb, centerPCB.kicad_sch]
2025-03-05 routed centerpcb
    [centerPCB.kicad_pcb, centerPCB.kicad_sch]
2025-03-05 Updated left header pins
    [centerPCB.kicad_sch, leftPCB.kicad_sch]
2025-03-05 Updated traces
    [centerPCB.kicad_pcb]
2025-03-06 Updated PCB designs for left and right boards
    [leftPCB.kicad_pcb, leftPCB.kicad_sch, rightPCB.kicad_pcb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]
2025-03-06 Finalized placement on left pcb
    [leftPCB.kicad_pcb, leftPCB.kicad_sch]
2025-03-06 Edited PCB for rotary encoder
    [rightPCB.kicad_pcb]
2025-03-06 Finalized center and left pcbs placemnt
    [centerPCB.kicad_pcb, centerPCB.kicad_sch, leftPCB.kicad_pcb]
2025-03-06 right pcb edits
    [rightPCB.kicad_pcb]
2025-03-06 saved schematic
    [rightPCB.kicad_sch]
2025-03-07 Added names on silk layer
    [centerPCB.kicad_pcb]
2025-04-13 Update lowPowerLED.py
    Re Enabled PiJuice charge % reading
2025-04-14 Fixed overlapping boards issues by cutting out areas in design Rerouted dpad traces to not interfere with each other Added "filesForOrder"
    [centerPCB-B_Cu.gbr, centerPCB-B_Mask.gbr, centerPCB-B_Paste.gbr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]
